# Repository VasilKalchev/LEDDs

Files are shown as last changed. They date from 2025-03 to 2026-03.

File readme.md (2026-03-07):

<p align=center>
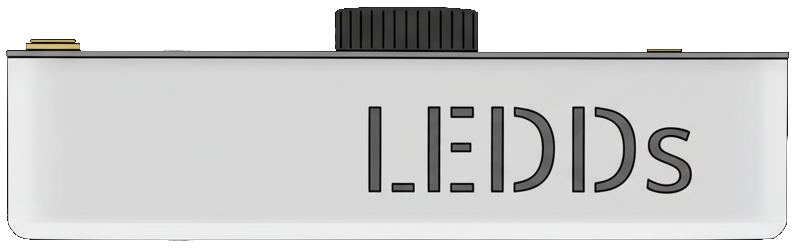
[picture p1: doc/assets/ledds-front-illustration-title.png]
LEDDs
  
</p>

<p align=center>trailing-edge dimmer for LED bulbs</p>

<div align=center>

  

</div>

**LEDDs** is an open-source hardware, DIY, smart dimmer for 230 V LED bulbs. It is built around the ESP32-C3-12F and is designed to sit on a desk or table, replacing standard inline cord switches.

The project consists of a **PCB**, a **3D-printable chassis**, and a **top plate** designed as a PCB. It runs [ESPHome](https://esphome.io) for integration with Home Assistant and features a **rotary encoder** so it can be controlled easily or used as a standalone device.

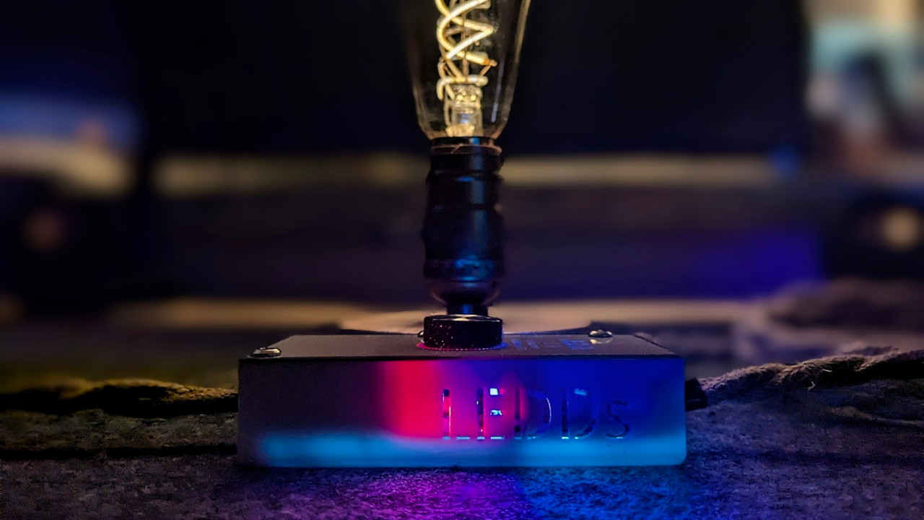
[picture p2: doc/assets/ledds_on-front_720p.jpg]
ledds


> [!CAUTION]
> **MAINS VOLTAGE:** This device operates at **230 VAC**. Touching live components can result in serious injury or death.
> * Only build if you have relevant experience with high-voltage electronics.
> * Always unplug before opening!
> * While the design includes safety features (fuse, MOVs), it is not a certified design and should be treated with caution.

## Table of contents
* [Is this project for you?](#is-this-project-for-you)
* [Why trailing-edge?](#why-trailing-edge)
* [Features](#star-features)
* [Specifications](#straight_ruler-specifications)
* [Release/fabrication of version 2.0](#releasefabrication-of-v20)
* [Repository structure](#open_file_folder-repository-structure)
* [Bill of materials](#euro-bill-of-materials)
* [Build](#hammer-build)
   * [Prerequisites](#prerequisites)
   * [1. Ordering the components](#1-ordering-the-components)
   * [2. PCB assembly instructions](#2-pcb-assembly-instructions)
   * [3. Flashing the firmware](#3-flashing-the-firmware)
   * [4. Preparing the enclosure](#4-preparing-the-enclosure)
   * [5. Final assembly](#5-final-assembly)
* [Usage](#bulb-usage)
   * [Control](#control)
   * [LED indicators](#led-indicators)
   * [Default light effects](#default-light-effects)
* [Versions, releases and compatibility](#page_with_curl-versions-releases-and-compatibility)
* [Contributing](#coffee-contributing)
* [License](#license)

---

## Is this project for you?
This project is suitable if you:
 - have experience with mains-powered electronics
 - want a LED bulbs dimmer for a desk

This project is NOT suitable if you:
 - are new to electronics
 - need a certified wall dimmer

## Why trailing-edge?
Most dimmers use **leading-edge** (TRIAC) dimming (designed for incandescent bulbs). They modulate power to the load by cutting the beginning of the AC half cycle. This creates a voltage spike that can cause buzzing and reduced lifespan in the capacitive power supplies found in LED bulbs.

**LEDDs uses trailing-edge dimming.** By using MOSFETs to cut the waveform at the *end* of the AC cycle, there isn't a positive voltage spike. This results in:
* reduced electrical noise and buzzing
* smoother dimming with reduced flicker
* lower minimum brightness levels

> The schematic and PCB can be viewed in [KiCanvas][kicanvas_v2_0].

## :star: Features
- **ESP32-C3** based with ESPHome firmware for integration with Home Assistant
- **Standalone** operation, doesn't require Home Assistant
- **Rotary encoder** control: rotate to dim, press+rotate for effects, press for on/off
- LEDs: red (rotation feedback), blue (status indicator), white (ambient)
- Included **enclosure design**: 100 mm × 51 mm × 25 mm - ideal for desk lamp modifications
- Low idle power: ~0.3 W
- Open source: MIT licensed

## :straight_ruler: Specifications

| Parameter | Value |
| --- | --- |
| Input voltage | 230 VAC |
| Maximum output power | 100 W |
| Idle power draw | ~0.3 W |
| Protections | fuse and MOVs |
| Microcontroller module | ESP32-C3-12F [^1] |
| Dimensions | 100 × 51 × 25 mm (W × D × H) |
| Connectivity | Wi-Fi, USB-C (programming) |

[^1]: Also compatible with ESP8266 ESP-12F, but not recommended.

> [!IMPORTANT]
> Designed for 230 VAC at 50 Hz.
>
> Usage with 120 VAC at 60 Hz will probably require adjusting the component values of the zero-cross and the voltage regulator circuits.

---

## Release/fabrication of v2.0

> **Status:** Verified working.
> The fabricated board from this release is fully functional. Minor issues may exist but do not affect operation: [/doc/releaselog.md v2.0][releaselog_v2_0].
>
> :memo: **Recommended for fabrication.**

<p align="center">
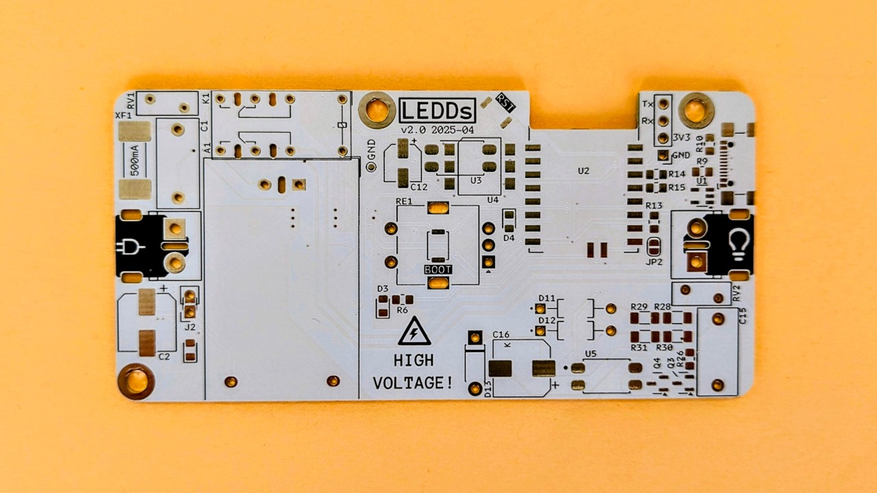
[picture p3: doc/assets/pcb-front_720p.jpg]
PCB front
  
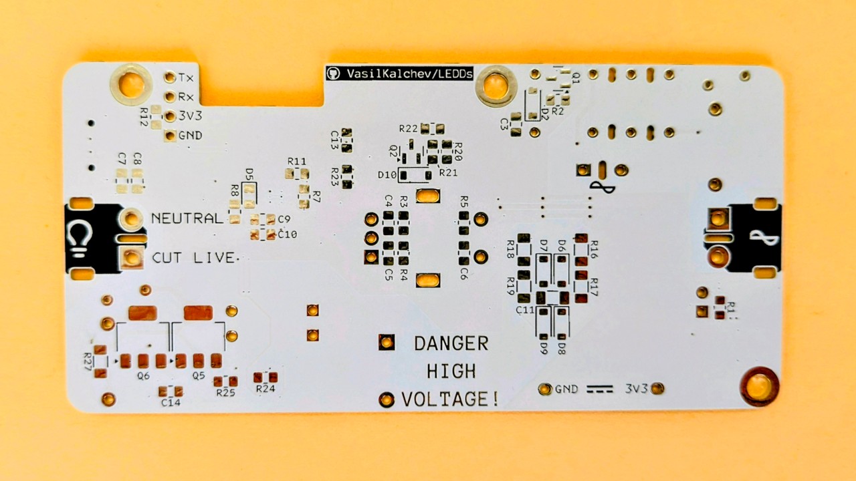
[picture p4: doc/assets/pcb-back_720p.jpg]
PCB back
  
</p>

---

## :open_file_folder: Repository structure
```

├── hw/                       # main PCB design (KiCad project)
│   ├── lib/                  # symbols and footprints
│   ├── assets/               # fonts and graphics
│   └── export/               # scripts for exporting gerbers, BOM and schematics/PCB PDFs
├── fw/                       # ESPHome YAML configurations and firmware binaries
├── doc/                      # additional documentation
│   ├── releaselog.md         # main PCB release log
│   ├── changelog.md          # main PCB change log
├── enclosure/
│   ├── chassis/              # 3D printable chassis
│   │   ├── releaselog.md     # chassis release log
│   │   ├── changelog.md      # chassis change log
│   │   ├── vX.Y-variant_a/
│   │   └── vX.Y-variant_b/
│   └── top_plate/            # top plate design (KiCad project)
│       ├── releaselog.md     # top plate release log
│       ├── changelog.md      # top plate change log
│       ├── vX.Y-variant_a/
│       └── vX.Y-variant_b/
└── img/                      # photos and renders
```

---

## :euro: Bill of materials
 - components: ~€15
 - PCB: €4 (ordered as prototype board)
 - top plate: €0-4 (can be combined with the main PCB)
 - chassis: €4-10 (when ordered)

Check out the BOM provided in the release bundle for complete components list.

## :hammer: Build

### Overview
Building LEDDs consists of four main steps:
 1. Ordering the PCB, the chassis and the components.
 2. Assembling the PCB.
 3. Flashing and configuring the firmware.
 4. Wiring and final assembly.

### Prerequisites
- skills: soldering [^2], experience with mains electricity
- tools: soldering iron, hot air gun (recommended), 3D printer or access to 3D printing service, multimeter

[^2]: Trickiest part is the USB-C port. The board can be ordered pre-assembled.

Download the [release bundle][dw_release_bundle_v2_0].

### 1. Ordering the components
  - **PCBs**: order the main PCB and the top plate PCB from your preferred fabricator
    - gerbers for JLCPCB: available in the bundle
    - for other fabricators - use KiCad to generate gerbers according to the manufacturer's instructions
  - **chassis**: choose a variant from the provided STL files

### 2. PCB assembly instructions
> [!TIP]
> Use the provided **interactive BOM** ("ibom.html") as a soldering guide.

<p align=center>
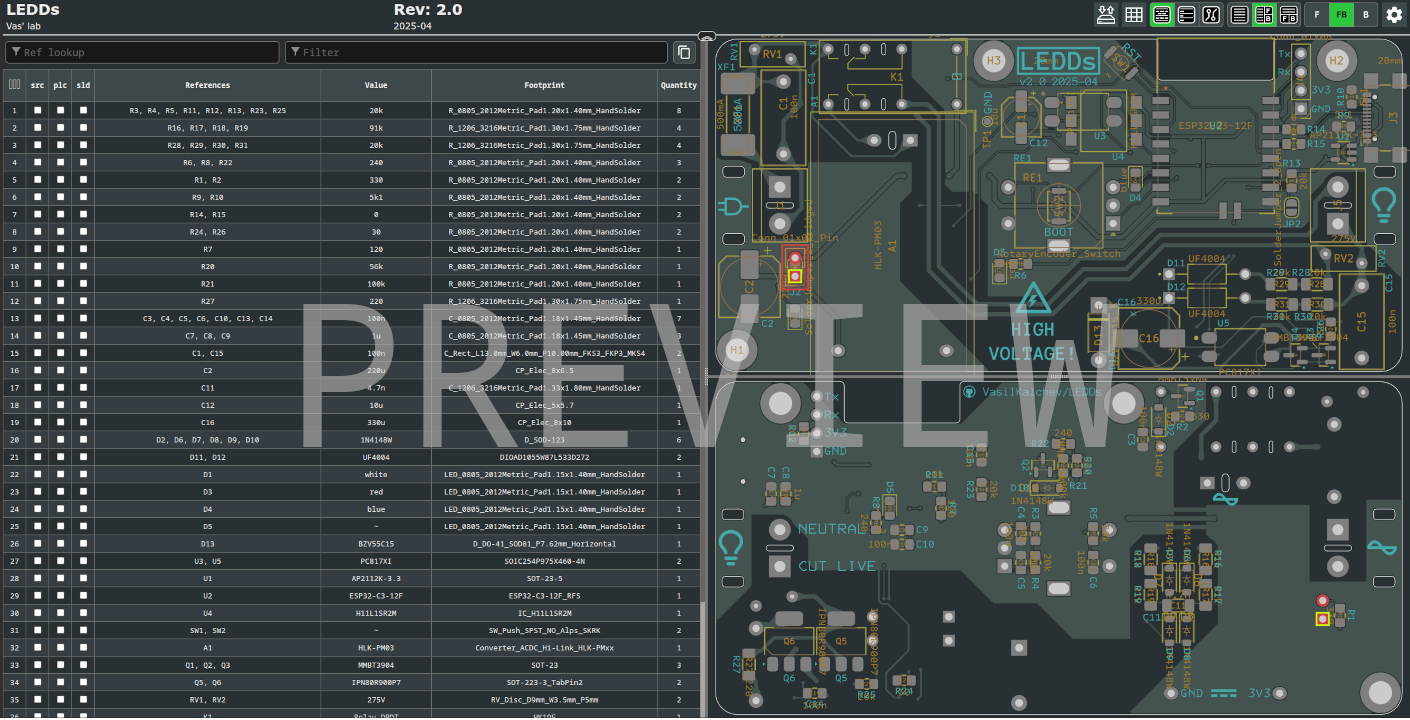
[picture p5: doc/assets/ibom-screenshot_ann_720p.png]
interactive BOM preview
  
</p>

#### Microcontroller module
<strong>ESP32-C3-12F (recommended)</strong>

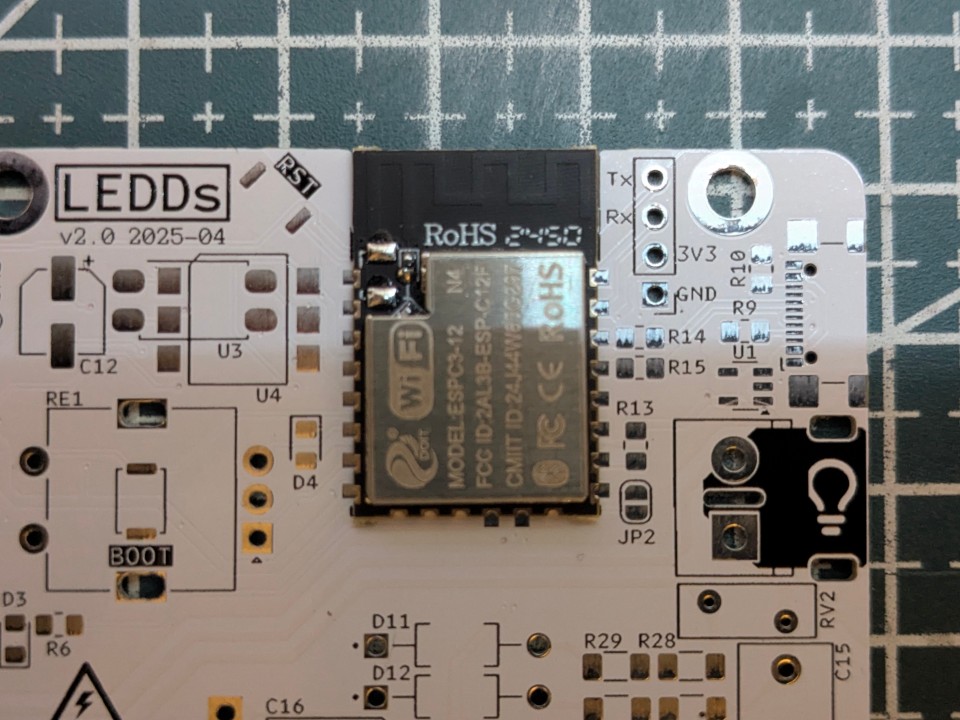
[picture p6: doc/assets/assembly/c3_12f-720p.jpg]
esp32-c3-12f


- solder R13

<details><summary><strong>ESP8266 ESP-12F (not recommended)</strong></summary>

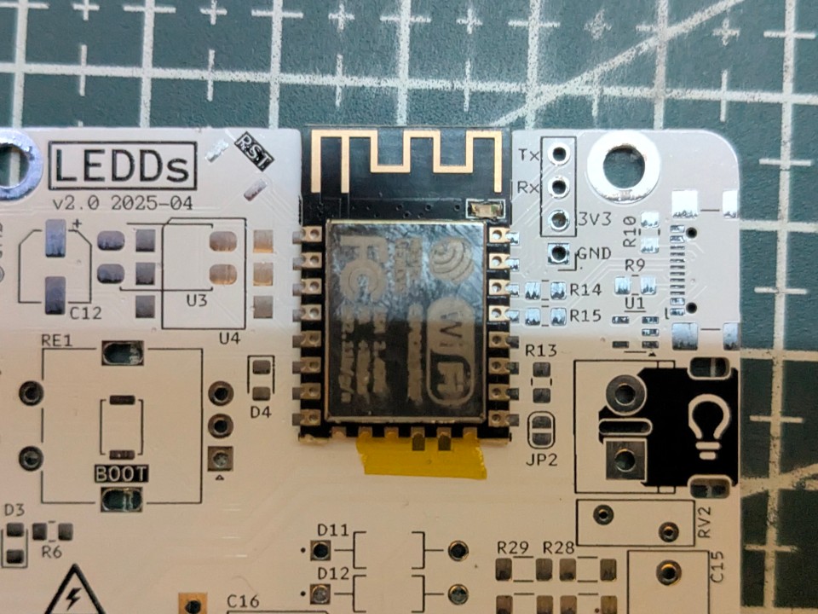
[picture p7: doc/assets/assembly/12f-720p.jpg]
esp-12f


- insulate pins 12 and 13 from the PCB pads using kapton/electrical tape
- solder JP2
- don't solder R13
- don't solder R6 and D3 ("led_1")
- don't solder R8 and D5 ("led_3")

ESP8266 doesn't support native USB and requires an external USB to serial adapter for programming.

</details>

#### Zero-cross optoisolator
The PCB has footprints for a choice between 2 optoisolators that connect the zero-cross signal to the MCU.

<strong>H11L1SR2M</strong>

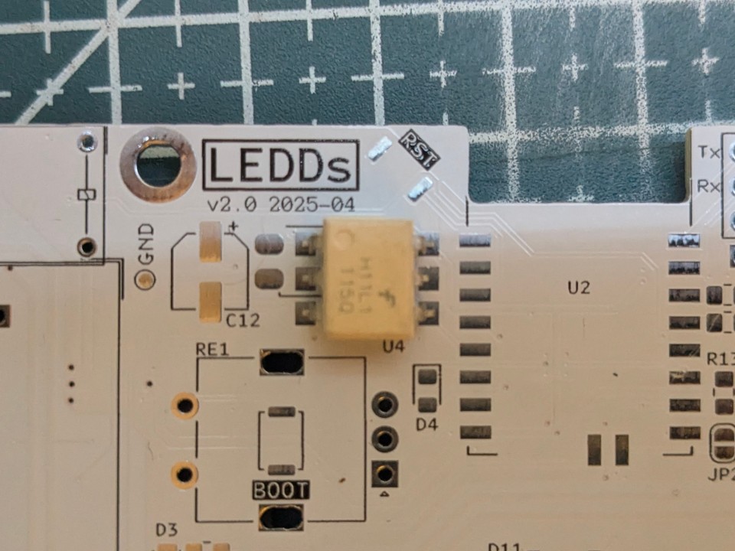
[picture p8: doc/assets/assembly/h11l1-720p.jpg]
h11l1


 - solder the optoisolator on footprint U4
 - solder C13

<details><summary><strong>PC817XI (not recommended)</strong></summary>

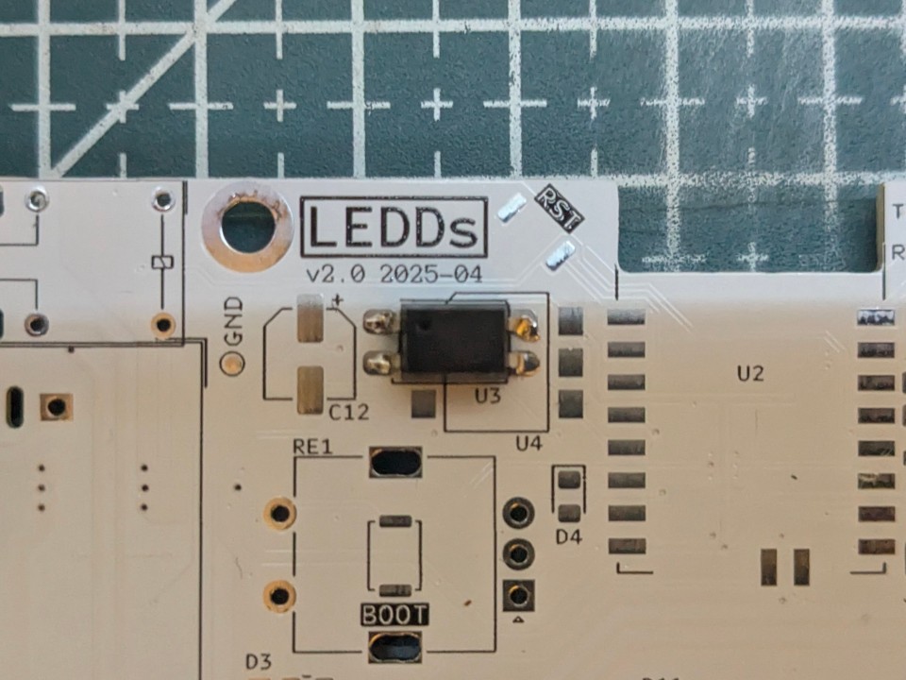
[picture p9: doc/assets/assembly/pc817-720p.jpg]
pc817


- solder the optoisolator on footprint U3
- no need to solder C13

This optoisolator is the same as the one used for controlling the MOSFET's gate, but didn't work well for the zero-cross circuit.

</details>

#### Skipping the relay
The relay is used to power off the mains part of the circuit when the load is turned off. This is intended as a peace of mind feature and can be omitted.

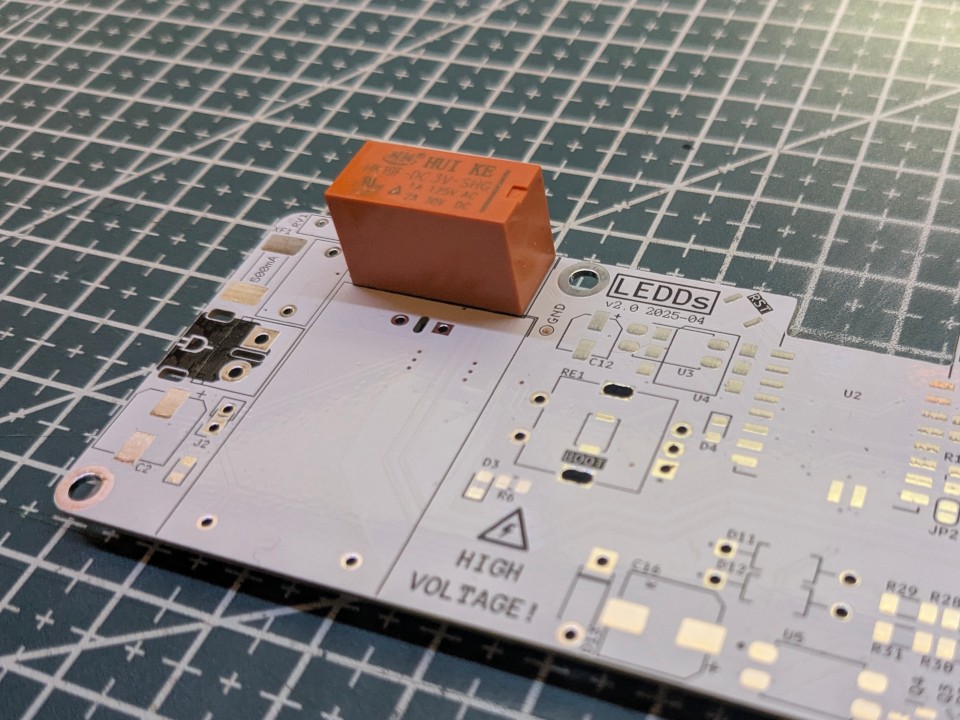
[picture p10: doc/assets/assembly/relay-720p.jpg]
relay


 - use a wire to short pin 11 to 14
 - use a wire to short pin 21 to 24
 - no need to solder C3, D2, R2 and Q1

#### Skipping the rotary encoder
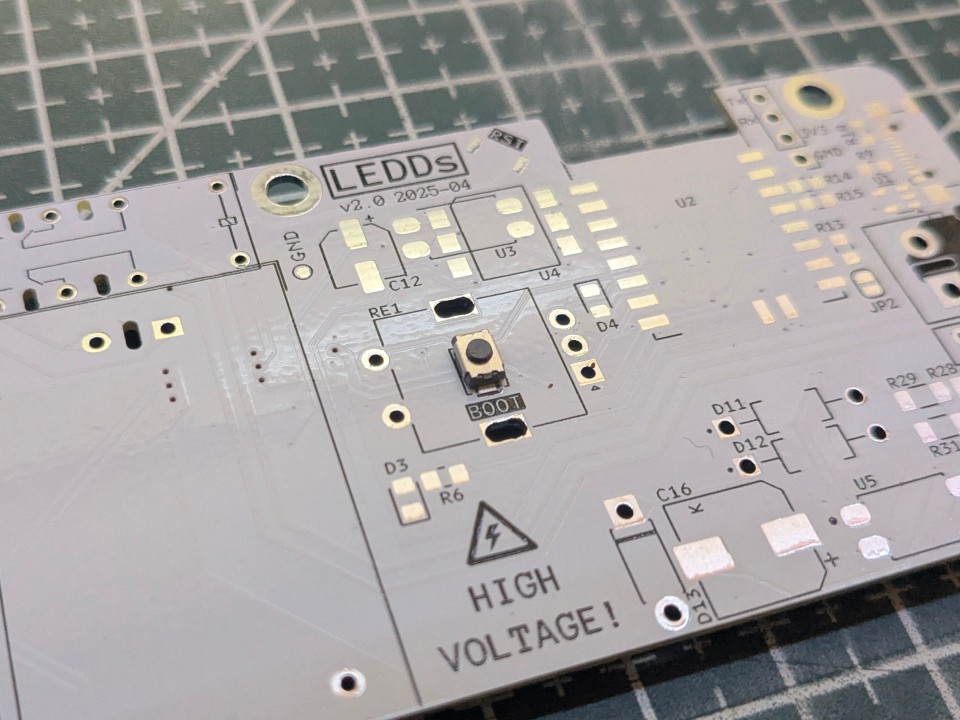
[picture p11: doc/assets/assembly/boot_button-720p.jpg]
boot button


If the rotary encoder is not required - solder a push button (SW2) so boot mode can be entered manually.

 - no need to solder R3, R4, C4, C5 and C6

A modified top plate (without a hole in the middle) is recommended for safety reasons (not currently available).

#### Using the UART header instead of the USB for programming *(not tested)*
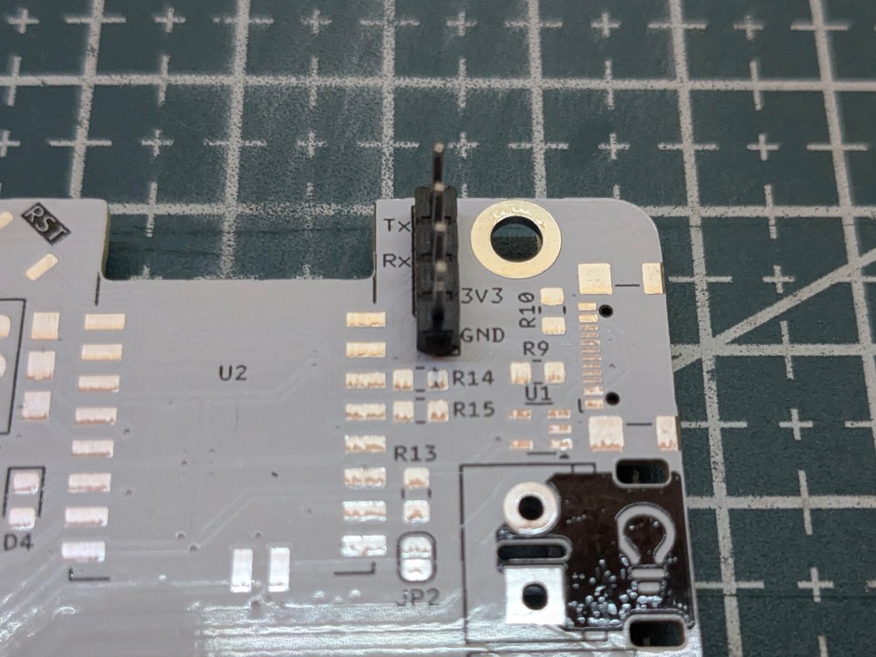
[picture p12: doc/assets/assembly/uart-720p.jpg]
uart


 - solder R12
 - solder header J4
 - no need to solder R9 and R10

Use a USB to serial adapter.

### 3. Flashing the firmware
 - Connect to the board via USB-C.
 - Use [ESPHome's web flasher](https://web.esphome.io/) to upload one of the provided firmware binaries.
   - hass.bin: Home Assistant + rotary encoder
   - web_server.bin: self hosted web server + rotary encoder
   - standalone: rotary encoder only
 - Set your Wi-Fi credentials using the ESPHome web flasher.
 - Test before wiring.

> [!TIP]
> The YAML configurations of the provided binaries are available under [/fw/esphome/yaml/](/fw/esphome/yaml/).

### 4. Preparing the enclosure
- plastic chassis: install the heat-set threaded inserts in the holes using a soldering iron
- resin chassis: no preparation needed

### 5. Final assembly
 - Mount a knob to the rotary encoder.
 - Place the PCB inside the chassis.
 - Screw the mains power cable to the terminal on the left (marked with a power plug). **Don't connect power until fully assembled.**
 - Screw the lamp socket cable to the terminal on the right (marked with a bulb).
 - Pass the screws through the top plate and place the spacers on the screws.
 - Screw the top plate through the PCB into the chassis.

## :bulb: Usage
### Control
**Directly** *(possible with all firmware variants)*:
 - **press**: on/off
 - **rotate**: brightness adjustment
 - **press + rotate**: cycle lighting effects

**Home Assistant** *(included in hass.bin)*:

Integrating the device in Home Assistant: https://esphome.io/guides/getting_started_hassio/#connecting-your-device-to-home-assistant.

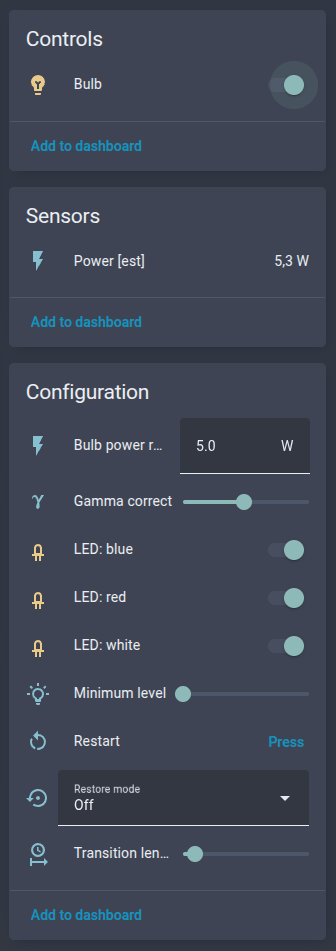
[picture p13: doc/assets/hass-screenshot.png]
screenshot of the device in Home Assistant


The "Configuration" section allows customization of the device:
 - **Bulb power rating**: input the power rating of the bulb, this is used for the power estimation sensor ("Power \[est\]").
 - **Gamma correct**: Adjust the dimming curve to appear linear to the human eye.
 - **Minimum level**: The lowest level at which the bulb emits light. *Note: this value needs to be updated every time gamma correction is changed.*
 - **Restore mode**: Initial state of the bulb when powered.
 - **Transition length**: How fast the bulb changes brightness in milliseconds.
 - **LED: red/blue/white**: set the ambient brightness of the LEDs.

**Web server** *(included in web_server.bin)*:
> This is useful if you don't have Home Assistant, but want to control the device remotely.

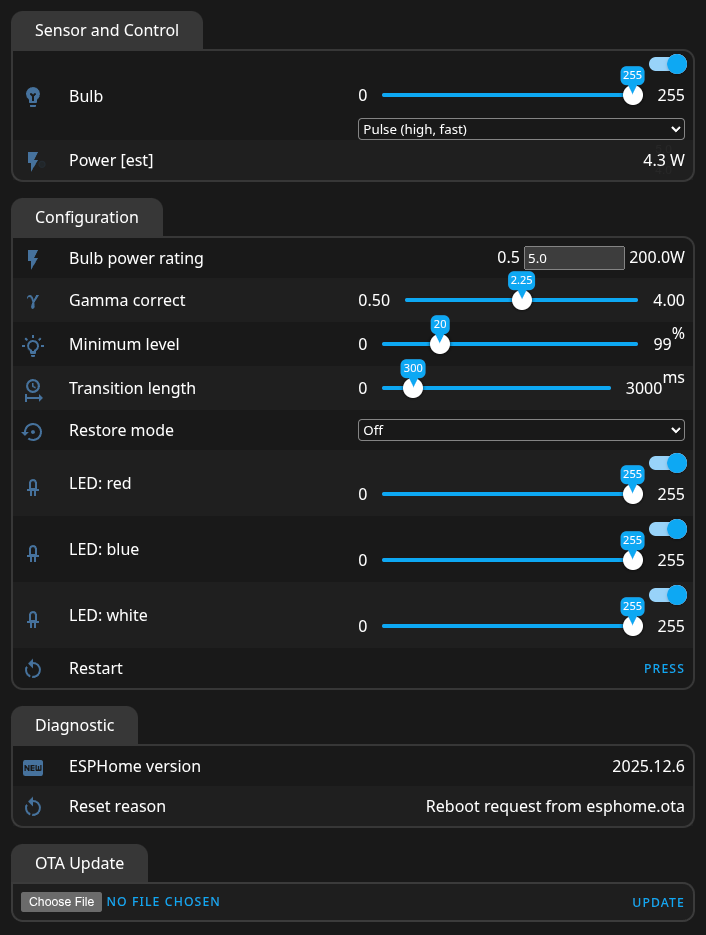
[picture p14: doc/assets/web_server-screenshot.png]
screenshot of the web UI


### LED indicators
There are three LEDs on the board:
 - **red (top, led_1):** ambient / rotation feedback
 - **blue (top, led_2):** ambient / status indicator
 - **white (bottom, led_3):** ambient

### Default light effects
Light effects can be cycled with the rotary encoder or chosen directly from a UI.

 - Pulse (low, fast)
 - Pulse (low, slow)
 - Pulse (high, fast)
 - Pulse (high, slow)
 - Pulse (full, fast)
 - Pulse (full, slow)
 - Flicker (soft)
 - Flicker (intense)

<!--
<div>
<p align="center">
  <img src="/doc/assets/effect-pulse_low_fast.gif" alt="" title="Pulse (low, fast)" width="25%" />
  <img src="/doc/assets/effect-pulse_low_slow.gif" alt="" title="Pulse (low, slow)" width="25%" />
  <img src="/doc/assets/effect-pulse_high_fast.gif" alt="" title="Pulse (high, fast)" width="25%" />
  <img src="/doc/assets/effect-pulse_high_slow.gif" alt="" title="Pulse (high, slow)" width="25%" />
</p>
<p align="center">
  <img src="/doc/assets/effect-pulse_full_fast.gif" alt="" title="Pulse (full, fast)" width="25%" />
  <img src="/doc/assets/effect-pulse_full_slow.gif" alt="" title="Pulse (full, slow)" width="25%" />
  <img src="/doc/assets/effect-flicker_soft.gif" alt="" title="Flicker (soft)" width="25%" />
  <img src="/doc/assets/effect-flicker_intense.gif" alt="" title="Flicker (intense)" width="25%" />
</p>
</div>
-->

## :page_with_curl: Versions, releases and compatibility
Each fabrication run results in a **GitHub release**.
- Semantic versioning (major.minor), no patch versions.
- PCB, chassis, and top plate are versioned independently.
- Same **major versions fit together**.

## :coffee: Contributing
Every type of contribution is welcome, like improvements or corrections to the:
- schematic/PCB design
- documentation
- enclosure (chassis and top panel) design
- ESPHome configuration

Contributions can be made as improvements or as variants (e.g. different enclosure design, ESPHome configuration, etc.).

```mermaid
gitGraph
    commit tag: "v1.0"
    branch improve_x
    checkout improve_x
    commit id: "Improve x"
    commit id: "Re-generate exports"
    commit id: "Update board documentation"
    checkout main
    merge improve_x tag: "v1.1"
    branch replace_y
    checkout replace_y
    commit id: "Replace y"
    commit id: "Generate exports"
    commit id: "Compile binaries"
    commit id: "Update all documentation"
    checkout main
    merge replace_y tag: "v2.0"
```

You're welcome to post your builds in [Discussions: Show and tell](https://github.com/VasilKalchev/LEDDs/discussions/categories/show-and-tell).

## License
This project is licensed under the **MIT License**.

---

**Disclaimer**: This project involves mains voltage electricity. The author assumes no liability for injury, damage, or regulatory violations. Build and use at your own risk. Ensure compliance with local electrical codes and regulations.

<!-- current version links -->

[kicanvas_v2_0]: https://kicanvas.org/?github=https%3A%2F%2Fgithub.com%2FVasilKalchev%2FLEDDs%2Ftree%2Fv2.0%2Fhw
[dw_release_bundle_v2_0]: https://github.com/VasilKalchev/LEDDs/releases/download/v2.0/LEDDs.v2.0.zip

[releaselog_v2_0]: /doc/releaselog.md#v20---2025-04-02

<!-- /current version links -->

<!-- checklist
<details>
<summary>/readme.md checklist</summary>

 - [x] set release result (template in releaselog.md)
 - [x] update the sections as needed
 - [x] comment out this checklist

</details>

-->
<!-- /checklist -->

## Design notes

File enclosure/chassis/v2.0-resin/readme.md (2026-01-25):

[Tinkercad: LEDDs chassis v2.0 (resin)](https://www.tinkercad.com/things/dSsVzKjQB6I-ledds-chassis-v20-resin)

<div>
<p align="center">
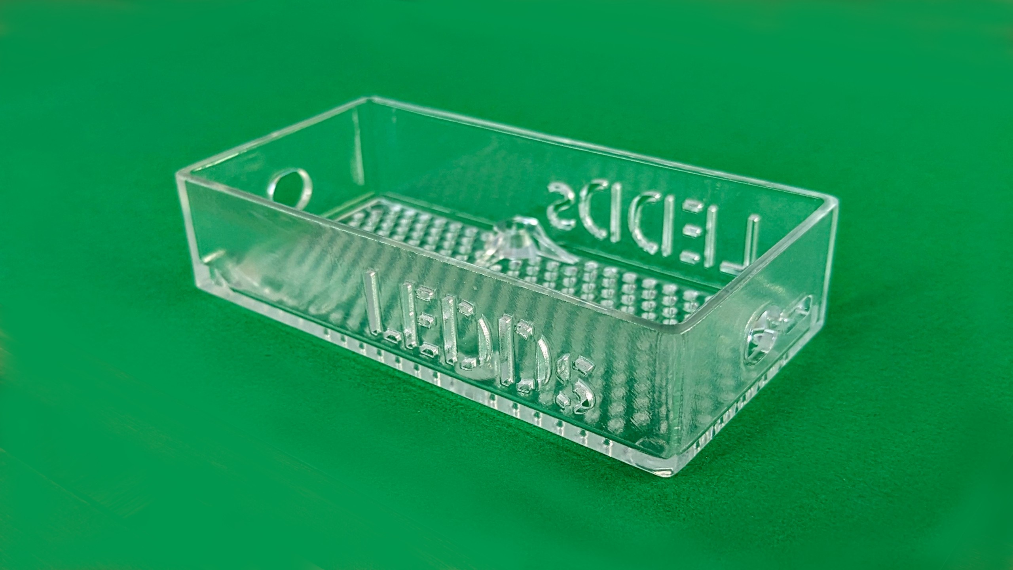
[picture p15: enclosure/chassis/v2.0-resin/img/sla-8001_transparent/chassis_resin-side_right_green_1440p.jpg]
chassis side
  
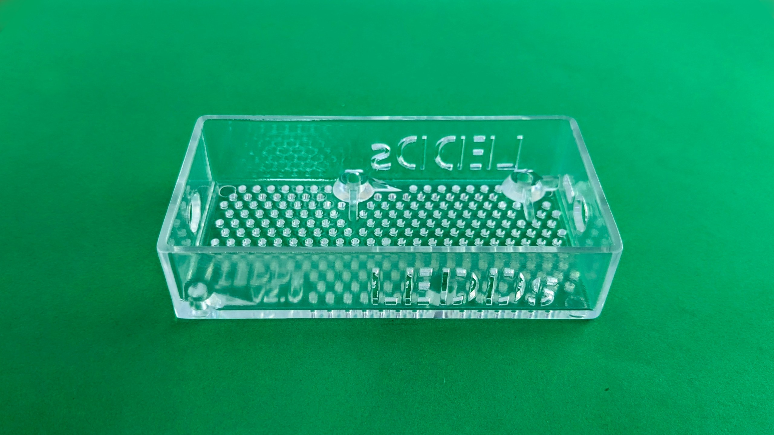
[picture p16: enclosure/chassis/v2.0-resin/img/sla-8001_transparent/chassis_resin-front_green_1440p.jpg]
chassis front
  
</p>
<p align="center">
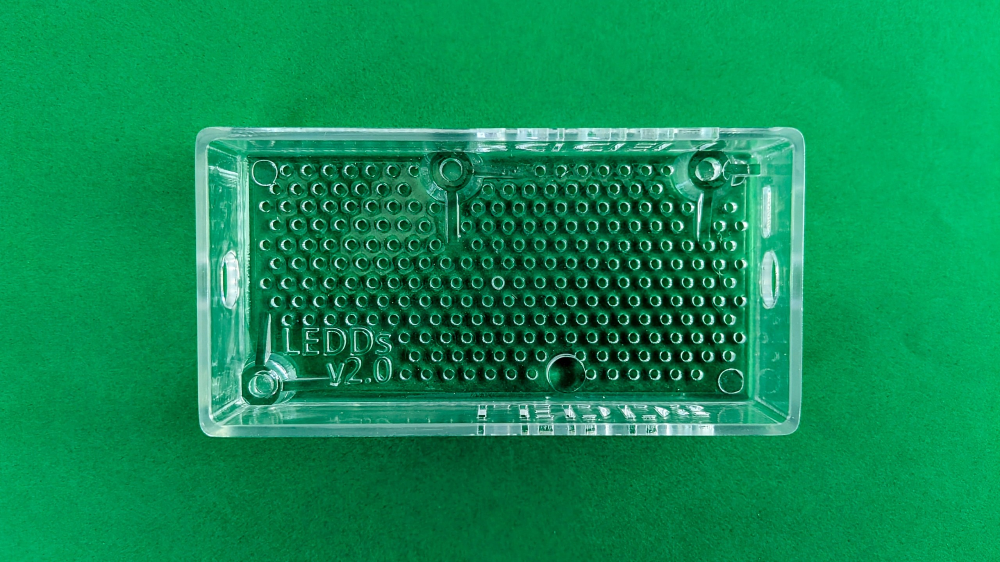
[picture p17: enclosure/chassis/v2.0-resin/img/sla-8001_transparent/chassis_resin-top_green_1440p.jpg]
chassis top
  
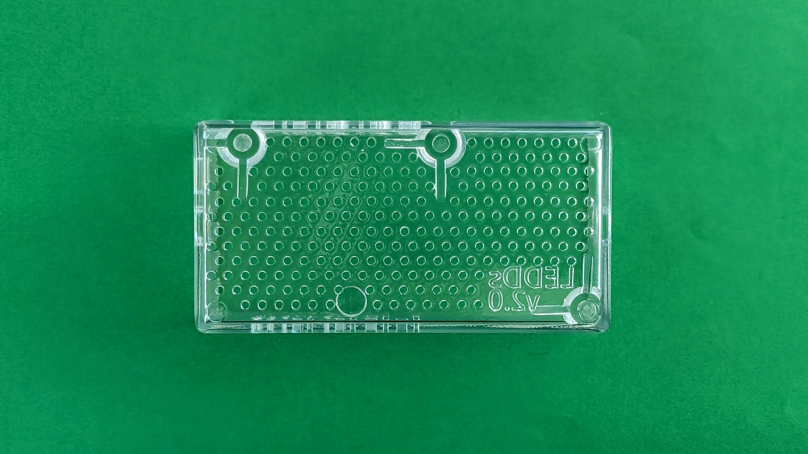
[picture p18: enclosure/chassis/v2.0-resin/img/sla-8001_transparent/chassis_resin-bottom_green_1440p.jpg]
chassis bottom
  
</p>
</div>

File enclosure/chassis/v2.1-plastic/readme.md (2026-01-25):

[Tinkercad: LEDDs chassis v2.1 (plastic)](https://www.tinkercad.com/things/8mwNKOLO64o-ledds-chassis-v21-plastic)

<div>
<p align="center">
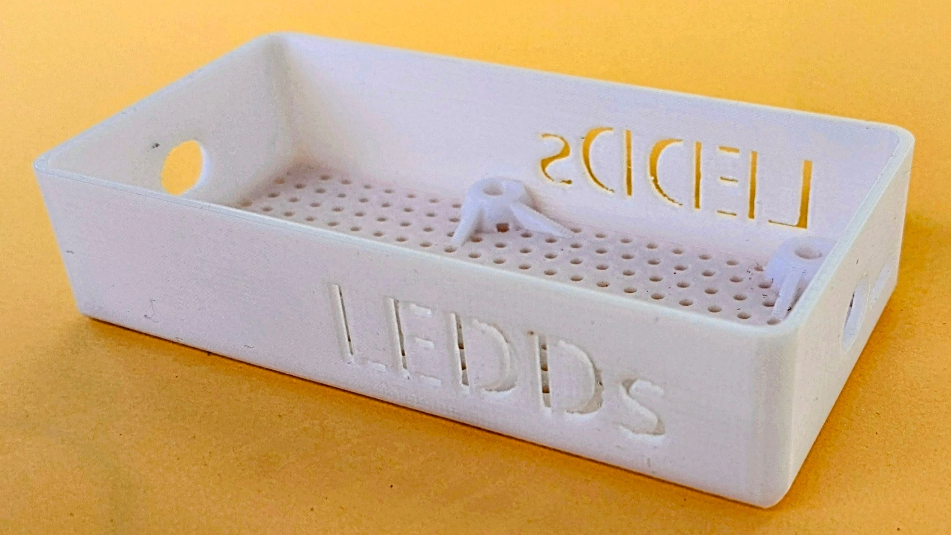
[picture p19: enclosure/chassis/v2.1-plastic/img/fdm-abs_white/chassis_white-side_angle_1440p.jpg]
chassis side
  
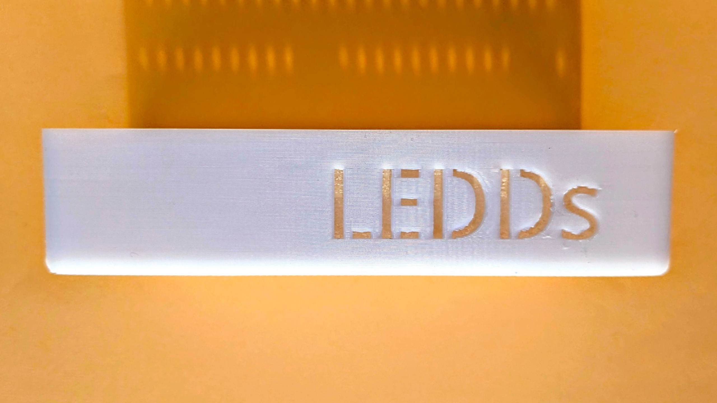
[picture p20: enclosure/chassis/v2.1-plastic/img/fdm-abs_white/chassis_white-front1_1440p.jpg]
chassis front
  
</p>
<p align="center">
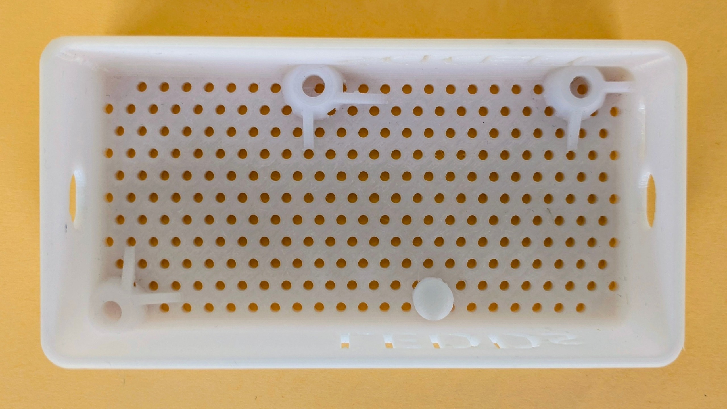
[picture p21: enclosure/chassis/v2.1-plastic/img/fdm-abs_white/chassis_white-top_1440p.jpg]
chassis top
  
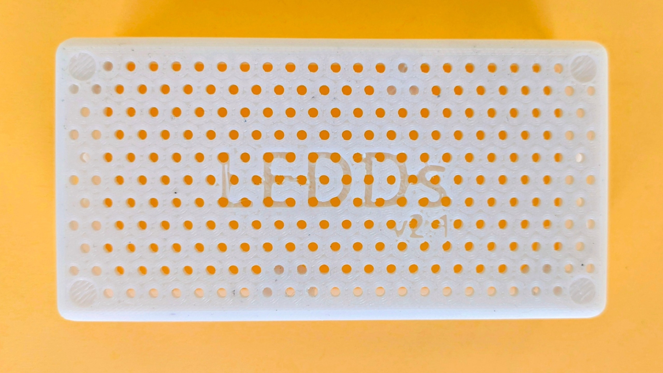
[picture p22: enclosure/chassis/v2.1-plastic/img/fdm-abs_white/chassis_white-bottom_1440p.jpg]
chassis bottom
  
</p>
</div>

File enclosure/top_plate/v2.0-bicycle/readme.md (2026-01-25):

<figure>
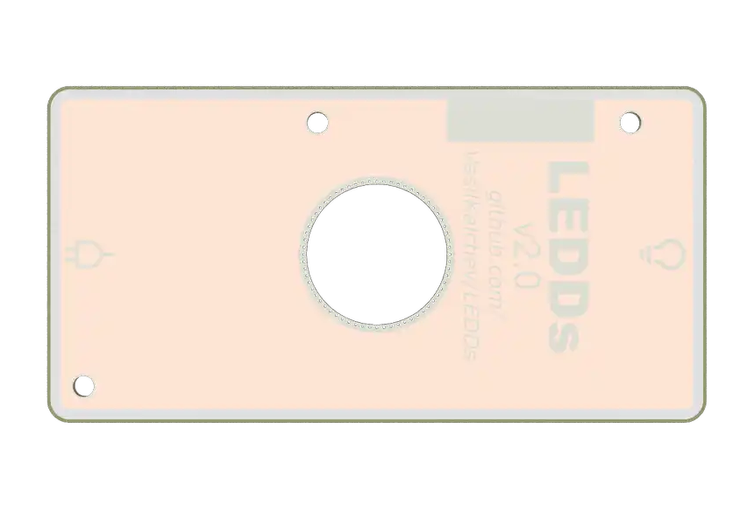
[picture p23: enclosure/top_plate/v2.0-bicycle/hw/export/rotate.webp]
rotating PCB render
  
<!--   <figcaption>smaller</figcaption> -->
</figure>

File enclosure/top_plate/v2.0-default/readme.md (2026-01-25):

<figure>
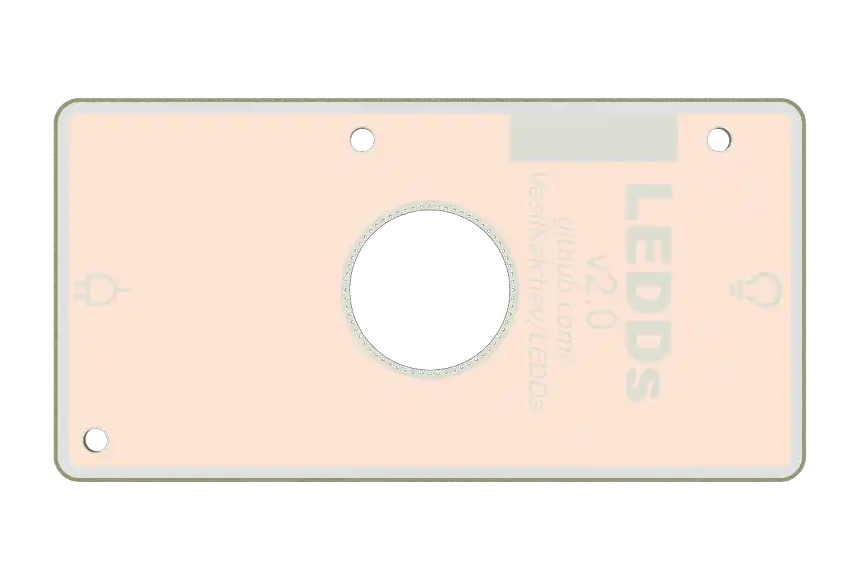
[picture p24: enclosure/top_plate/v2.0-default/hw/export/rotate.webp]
rotating PCB render
  
<!--   <figcaption>larger</figcaption> -->
</figure>

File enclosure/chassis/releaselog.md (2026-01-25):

# Chassis release log
Printing results.

## v2.1-plastic (FDM - ABS, white) - 2025-04-20

> The printed chassis from version 2.1 works without problems!
>
> :tada: Recommended for printing.

### Properties:
 - Fabricator: JLCPCB
 - Dimensions: 10×5.1×2.3cm
 - Volume: 19.46cm³
 - Surface area: 246.48cm²
 - 3D Technology: FDM (plastic)
 - Material: ABS
 - Colors: white
 - Surface finish: no

## v2.0-resin (SLA - 8001 resin, transparent) - 2025-04-03

> The printed chassis from version 2.0 works, but has some minor issues.
>
> :grey_exclamation: Obsolete.

### Properties:
 - Fabricator: JLCPCB
 - Dimensions: 10×5.1×2.3cm
 - Volume: 21.15cm³
 - Surface area: 248.42cm²
 - 3D Technology: SLA (resin)
 - Material: 8001 resin
 - Colors: transparent
 - Surface finish: oil spraying

### Problems
#### Minor
 - USB receptacle barely fits in the cutout
 - transparency doesn't go well with colored top plate

## v2.0-plastic (FDM - TPU translucent) - 2025-04-03

> The printed chassis from version 2.0 works, but has some minor issues.
>
> :grey_exclamation: Obsolete.

### Properties:
 - Fabricator: JLCPCB
 - Dimensions: 10×5.1×2.3cm
 - Volume: 21.15cm³
 - Surface area: 248.42cm²
 - 3D Technology: FDM (plastic)
 - Material: TPU
 - Colors: translucent
 - Surface finish: no

### Problems
#### Minor
 - USB receptacle barely fits in the cutout
 - the material is not suitable for a case
 - the color doesn't go well with the top plate

## v1.0 (FDM - PLA, white) - 2025-02-17

> The printed chassis from version 1.0 works, but has some minor issues.
>
> :grey_exclamation: Obsolete.

### Properties:
 - Fabricator: JLCPCB
 - Dimensions: 10×5.1×2.3cm
 - Volume: 22.55cm³
 - Surface area: 232.44cm²
 - 3D Technology: FDM (plastic)
 - Material: PLA
 - Colors: white
 - Surface finish: no

### Problems:
#### Minor
 - the programming header is not reachable through the cutout
 - the side name cutout is partly covered by the AC-DC converter

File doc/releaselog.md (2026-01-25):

# Release log

## v2.0 - 2026-01-26
### Hightlights
 - Switched MCU module to **ESP32-C3-12F**.
 - Added **USB-C** port for programming.

### Changes
 - Replaced module ESP-12 (ESP8266) with module ESP32-C3-12F (ESP32-C3).
 - Added USB-C.
 - Added 3.3 V linear regulator for powering the MCU through the USB only.
 - PCB layout adjustments.

### Compatibility notes
 - Older enclosures (chassis and top plate) from v1.y are not compatible with the new PCB.
 - UART header remains available, but the auto-programming circuit is removed.

### Upgrade impact
 - Firmware must target ESP32-C3.
 - Devices can be programmed directly over USB-C.

---

<p align="center">
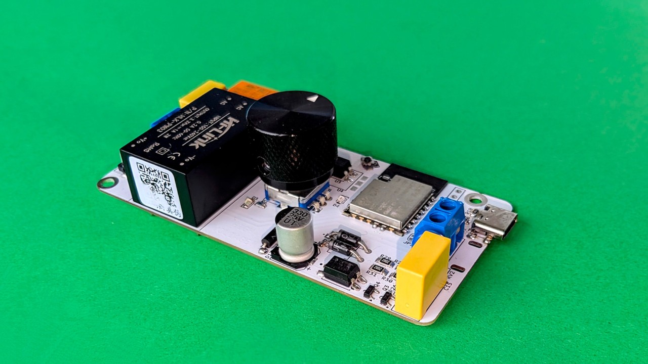
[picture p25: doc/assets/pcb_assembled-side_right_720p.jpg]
assebmled main PCB
  
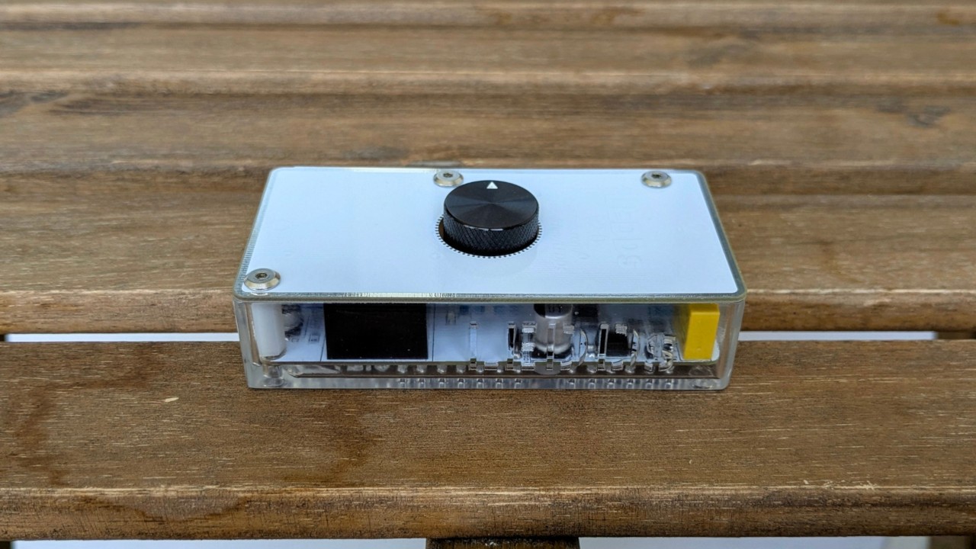
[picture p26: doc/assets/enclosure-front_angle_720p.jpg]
assembled project
  
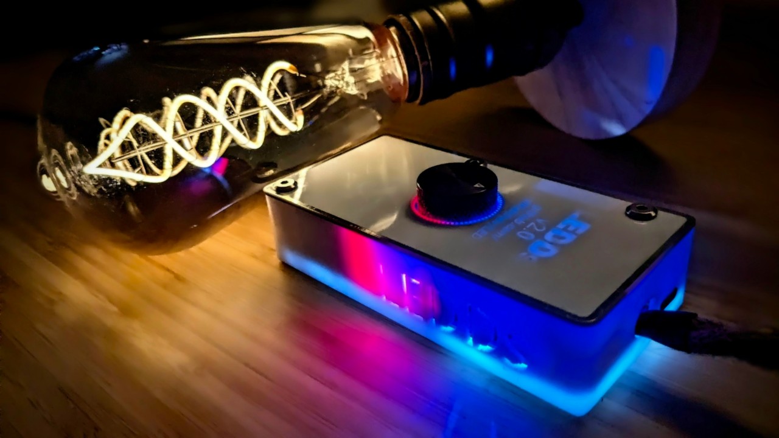
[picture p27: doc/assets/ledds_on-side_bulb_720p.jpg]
turned on
  
</p>


> **Status:** Verified working.
> The fabricated board from this release is fully functional. Minor issues may exist but do not affect operation.
>
> :memo: **Recommended for fabrication.**

### Fabbrication properties:
 - Fabricator: JLCPCB
 - Material: FR4 (Tg 135)
 - Layers: 2
 - **PCB thickness: 1 mm** [^1]
 - Solder mask color: white
 - Silkscreen: black
 - Surface finish: HASL (with lead)
 - Copper weight: 1 oz
 - Via covering: tented
 - Board outline tolerance: +-0.2 mm
 - Appearance quality: IPC Class 2 Standard
 - Silkscreen technology: Ink-jet/screen printing

### Issues
#### Minor
 - module ESP32-C3-12F isn't an official module and isn't available from distributors
 - red LED is only visible from one side

---

## v1.0 - 2025-02-17

<p align="center">
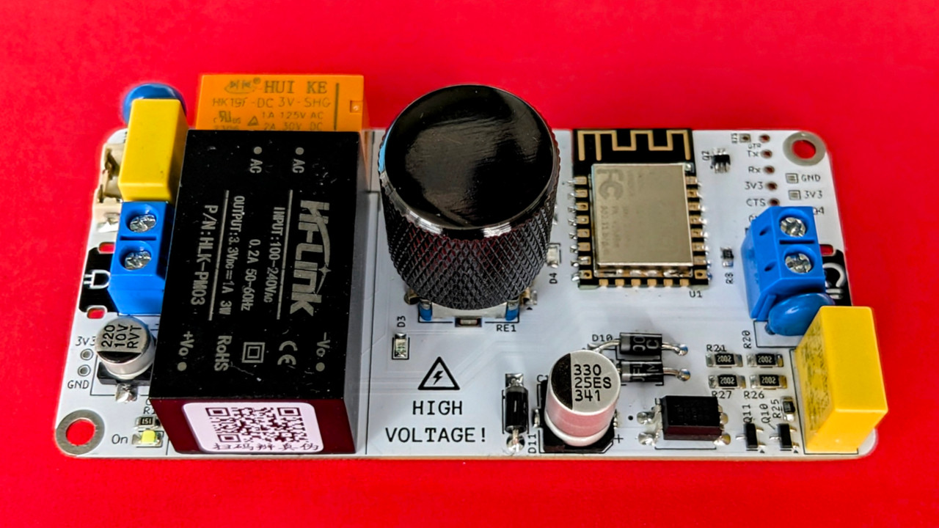
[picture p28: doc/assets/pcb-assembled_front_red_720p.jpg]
PCB - assembled, front PCB - assembled, side
  
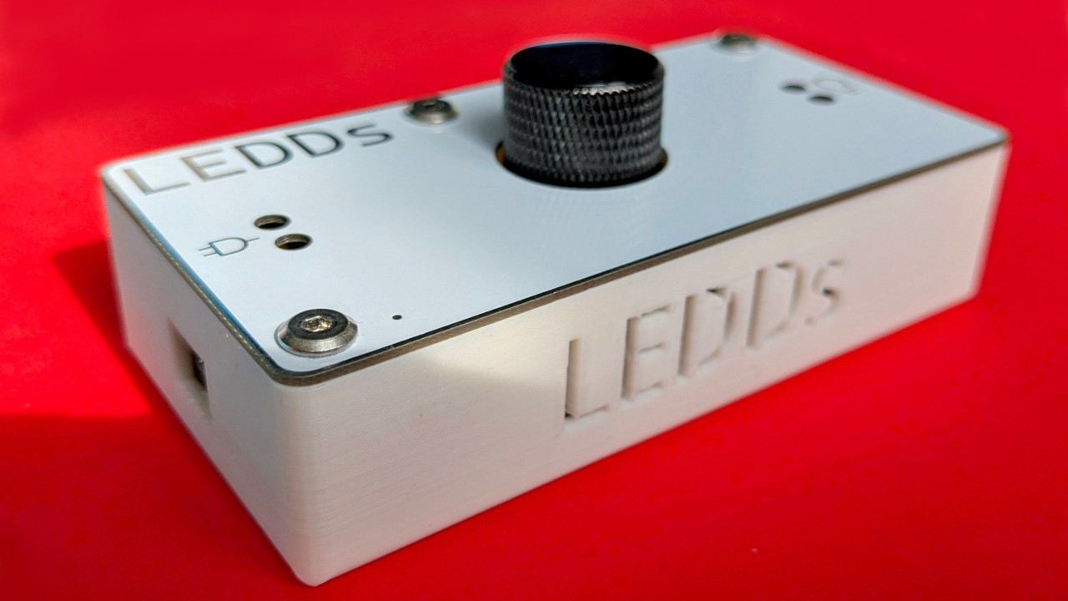
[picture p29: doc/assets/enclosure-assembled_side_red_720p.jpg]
Enclosure - assembled, side
  
</p>

---


> **Status:** Verified working.
> The fabricated board from this release is fully functional. Minor issues may exist but do not affect operation.
>
> :grey_exclamation: **Obsolete!**

### Fabrication properties:
 - Fabricator: JLCPCB
 - Material: FR4 (Tg 135)
 - Layers: 2
 - **PCB thickness: 1 mm** [^1]
 - Solder mask color: white
 - Silkscreen: black
 - Surface finish: HASL (with lead)
 - Copper weight: 1 oz
 - Via covering: tented
 - Board outline tolerance: +-0.2 mm
 - Appearance quality: IPC Class 2 Standard
 - Silkscreen technology: Ink-jet/screen printing

### Issues
#### Minor
 - ESP8266 is an obsolete MCU
 - R14/15/18/19 have non-standard values
 - zip-tie holes are too small
 - silkscreen with GitHub link is barely readable
 - relay pins cutouts are very close to the edge of the board
 - GPIO2 is connected to both led_1 and ESP-12's on-board LED

[^1]: Important for fit with the height of the chassis and the length of the spacers.

<!-- checklist

<details>
<summary>/releaslog.md checklist</summary>

 - [x] complete [/hw/project_checklist.md](/hw/project_checklist.md)
 - [x] fabricate
 - [x] assembly and test

 - [ ] FW

 - [x] add version with changes to [/doc/changelog.md](/doc/changelog.md)
 - [x] add version with fabrication result to [/doc/releaselog.md](/doc/releaselog.md)

 - [ ] use the scripts in [/hw/export/] to generate "release" files
 - [ ] complete [/doc/assets/readme/readme.md](/doc/assets/readme/readme.md) checklist
 - [ ] complete [/readme.md](/readme.md) checklist

 - [x] mark older boards of this major version as obsolete (in [/doc/releaselog.md](/doc/releaselog.md) and in repository releases)

 - [x] delete [/hw/project_checklist.md](/hw/project_checklist.md)

List of checklists inside the repository:
 - [/hw/project_checklist.md](/hw/project_checklist.md)
 - [/fw/readme.md](/fw/readme.md)
 - [/doc/assets/readme/readme.md](/doc/assets/readme/readme.md)
 - [/readme.md](/readme.md)

</details>

-->

<!-- release assessment templates (new)

![Status: Great](https://img.shields.io/badge/Great-limegreen?style=for-the-badge&label=Release/fabrication%20result)
> **Status:** Great release.
> The fabricated board works without any known issues.
>
> :tada: **Recommended for fabrication!** | :grey_exclamation: **Obsolete!**

---

![Status: Stable](https://img.shields.io/badge/Stable-brightgreen?style=for-the-badge&label=Release/fabrication%20result)
> **Status:** Verified working.
> The fabricated board from this release is fully functional. Minor issues may exist but do not affect operation: [releaselog](/doc/releaselog.md#vXY---202Y-MM-DD).
>
> :memo: **Recommended for fabrication.** | :grey_exclamation: **Obsolete!**

---

![Status: With issues](https://img.shields.io/badge/Functional_(w%2F_Caveats)-yellow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)
> **Status:** Functional with modifications.
> This board works, but has signifacant issues: [releaselog](/doc/releaselog.md#vXY---202Y-MM-DD).
>
> :grey_exclamation: Use [version X.Y] for fabrication or wait for a fix.

---

![Status: Broken](https://img.shields.io/badge/Do_Not_Use-firebrick?style=for-the-badge&label=Release/fabrication%20result)

> **Status:** Critical faults.
> The fabricated board from this release has significant design flaws and does not function correctly: [releaselog](/doc/releaselog.md#vXY---202Y-MM-DD).
>
> :stop_sign: **Do not fabricate.** Use [Version X.Y] instead.

---

![Status: WIP](https://img.shields.io/badge/In_development-lightgrey?style=for-the-badge&label=Release/fabrication%20result)
> **Status:** Work in progress.
> This branch is currently in active development and may be unstable.
>
> :hourglass_flowing_sand: **Wait for release** or use [Version X.Y].

---

![Status: Untested](https://img.shields.io/badge/Untested_fix-blueviolet?style=for-the-badge&label=Release/fabrication%20result)
> **Status:** Design fix (not yet fabricated).
> This release patches bugs found in vX.X. The design is theoretically correct but has not been physically verified.
>
> :memo: Check the latest [release note of this version](https://github.com/VasilKalchev/LEDDs/releases/tag/vX.Y) for a possible update on the fabrication status.

-->

<!-- release assessment templates (old)

<details>
<summary>release assessment templates</summary>

![bad fabrication](https://img.shields.io/badge/bad-firebrick?style=for-the-badge&label=Release/fabrication%20result)
> The fabricated board from release vX.Y doesn't work: [releaselog](/doc/releaselog.md#vXY---202Y-MM-DD).
>
> :grey_exclamation: Use [version X.Y] for fabrication or wait for a fix.

---

![poor fabrication](https://img.shields.io/badge/poor-orangered?style=for-the-badge&label=Release/fabrication%20result)
> The fabricated board from release vX.Y works, but has significant problems: [releaselog](/doc/releaselog.md#vXY---202Y-MM-DD).
>
> :grey_exclamation: Use [version X.Y] for fabrication or wait for a fix.

---

![average fabrication](https://img.shields.io/badge/average-yellow?style=for-the-badge&label=Release/fabrication%20result)
> The fabricated board from release vX.Y works, but has some issues: [releaselog](/doc/releaselog.md#vXY---202Y-MM-DD).
>
> :grey_exclamation: Use [version X.Y] for fabrication or wait for a fix.

---

![good fabrication](https://img.shields.io/badge/good-greenyellow?style=for-the-badge&label=Release/fabrication%20result)

> The fabricated board from release vX.Y works; it has some minor issues: [releaselog](/doc/releaselog.md#vXY---202Y-MM-DD).
>
> :memo: Recommended for fabrication! | :grey_exclamation: Obsolete!

---

![very good fabrication](https://img.shields.io/badge/very%20good-lawngreen?style=for-the-badge&label=Release/fabrication%20result)

> The fabricated board from release vX.Y works; it has a few minor issues: [releaselog](/doc/releaselog.md#vXY---202Y-MM-DD).
>
> :memo: Recommended for fabrication! | :grey_exclamation: Obsolete!

---

![great fabrication](https://img.shields.io/badge/great-limegreen?style=for-the-badge&label=Release/fabrication%20result)
> The fabricated board from release vX.Y works without any known issues!
>
> :tada: Recommended for fabrication! | :grey_exclamation: Obsolete!

---

![in development](https://img.shields.io/badge/in_development-dimgrey?style=for-the-badge&label=Release/fabrication%20result)
> This version is currently in development...
>
> :hourglass_flowing_sand: Wait for the release or use [version X.Y] for fabrication.

---

![will not fabricate](https://img.shields.io/badge/won\'t_be_fabricated-firebrick?style=for-the-badge&label=Release/fabrication%20result)
> Release vX.Y won't be fabricated, because ... .
>
> :exclamation: Browse [repository releases][repo_releases] for a better version.

---

![fix, not fabricated](https://img.shields.io/badge/fix%20(not%20fabricated)-indigo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)
> [Release vX.Y](/doc/releaselog.md#vX.Y) is a minor fix for vX.Y and was not fabricated at the time of release.
>
> :memo: Check the latest [release note of this version](https://github.com/VasilKalchev/LEDDs/releases/tag/vX.Y) for a possible update on the fabrication status.

</details>

-->

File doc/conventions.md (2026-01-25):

# Conventions

## Versioning
### Hardware (board)
Board releases are made with a major and a minor version (e.g. "LEDDs v1.2").

The major version is incremented when making incompatible changes to the board (e.g. pin rearrangement). The minor version is incremented for fixes or small additions that preserve compatibility with the firmware and the enclosure.

### Enclosure
The chassis and top plate's major versions correspond with the board's major version that they are compatible with.

The minor version is incremented for improvements.

Variants can be specified for different materials or cosmetic changes.
The chassis version must specify the material they are designed for, because of the different thread hole diameters.

### Examples:
#### Boards
`v1.0`: major version 1, minor version 0, original variant

#### Chassis
`v1.3-plastic`: compatible with all boards and plates versioned 1.Y, minor version 3, variant for FDM plastic (thread holes for inserts)
`v2.0-plastic`: compatible with all boards and plates versioned 2.Y, minor version 0, variant for SLA resin (thread holes direct screwing)

#### Top plates
`v3.1`: compatible with all boards and chassis versioned 3.Y, minor version 1, original variant
`v4.2-no_knob`: compatible with all boards and chassis versioned 4.Y, minor version 2, variant without knob cutout

## Development and release
### Before starting development
New board versions are developed in a separate branch.

### During development
Every change to the board is documented in [changelog.md](changelog.md).

### Before release
The [release_checklist.md](release_checklist.md) is completed.

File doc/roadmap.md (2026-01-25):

# Roadmap

This document outlines planned work for upcoming versions.
Items may change based on feedback and priorities.

## Next release (v3.0)
 - change MCU to ESP32-C3-WROOM-02
 - consolidate opto-isolators
 - remake whole case design in FreeCAD
 - match BOM to a distributor
 
## Short term

## Mid term

## Long term / ideas
 - smaller AC-DC converter

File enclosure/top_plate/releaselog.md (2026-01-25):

# Top plate release log
Fabrication results.

## v2.0 - 2025-04-02


> The fabricated top plate from version 2.0 works, but has some minor issues.
>
> :memo: Recommended for fabrication!

### Properties:
 - Fabricator: JLCPCB
 - Material: FR4 (Tg 135)
 - Layers: 2
 - PCB thickness: 1 mm
 - Solder mask color: white
 - Silkscreen: black
 - Surface finish: HASL (with lead)
 - Copper weight: 1 oz
 - Via covering: tented
 - Board outline tolerance: +-0.2 mm
 - Appearance quality: IPC Class 2 Standard
 - Silkscreen technology: Ink-jet/screen printing

### Problems
#### Minor
 - the holes around the knob cutout are too close to the edge
 - knob cutout is too wide

## v1.0 - 2025-02-17


> The fabricated top plate from version 1.0 works, but has some minor issues.
>
> :grey_exclamation: Obsolete.

### Properties:
 - Fabricator: JLCPCB
 - Material: FR4 (Tg 135)
 - Layers: 2
 - PCB thickness: 1 mm
 - Solder mask color: white
 - Silkscreen: black
 - Surface finish: HASL (with lead)
 - Copper weight: 1 oz
 - Via covering: tented
 - Board outline tolerance: +-0.2 mm
 - Appearance quality: IPC Class 2 Standard
 - Silkscreen technology: Ink-jet/screen printing

### Problems:
#### Minor
 - RST hole is too small
 - terminal screw holes are too small
 - it'll be better if the board can be rotated

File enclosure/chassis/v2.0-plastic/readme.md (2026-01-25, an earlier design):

[Tinkercad: LEDDs chassis v2.0 (plastic)](https://www.tinkercad.com/things/eWag09gYZm1-ledds-chassis-v20-plastic)

<div>
<p align="center">
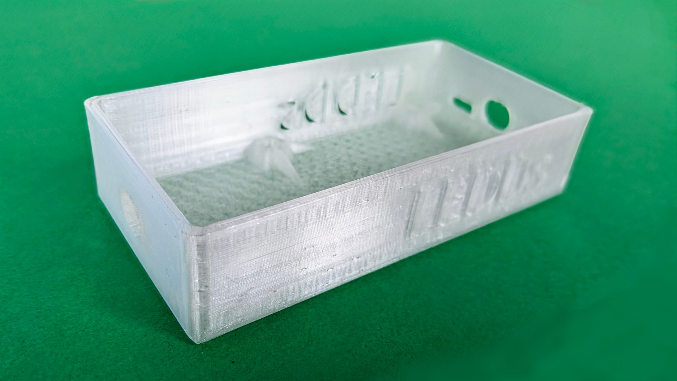
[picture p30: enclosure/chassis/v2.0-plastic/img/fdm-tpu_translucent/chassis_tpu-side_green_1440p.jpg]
chassis side
  
</p>
<p align="center">
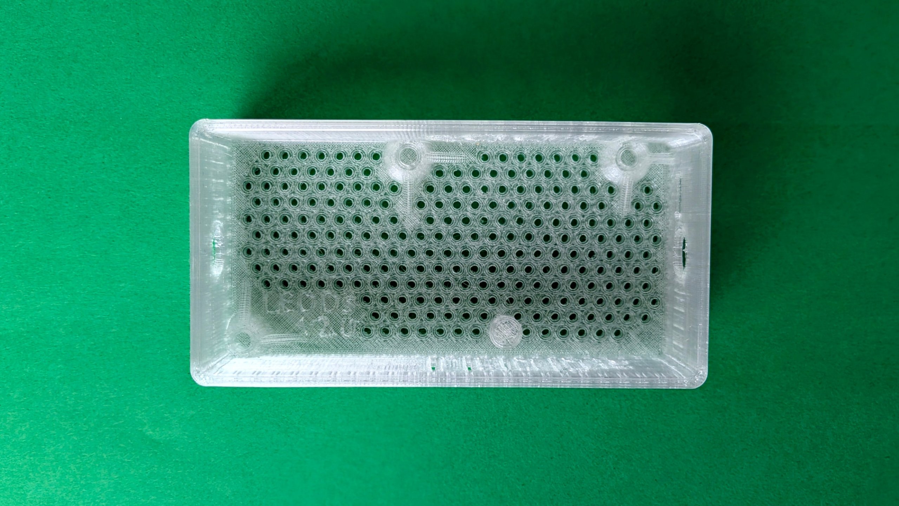
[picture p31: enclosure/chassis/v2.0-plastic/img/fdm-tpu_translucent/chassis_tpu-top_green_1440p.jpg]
chassis top
  
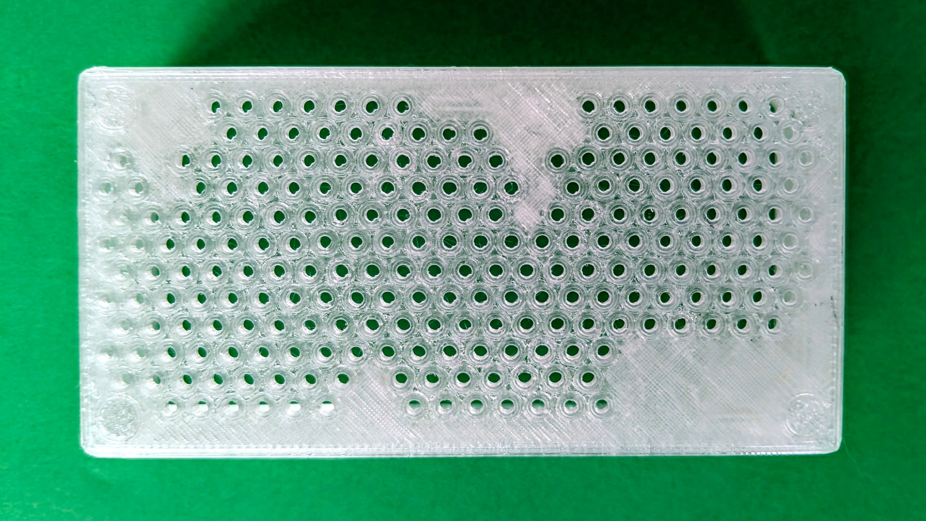
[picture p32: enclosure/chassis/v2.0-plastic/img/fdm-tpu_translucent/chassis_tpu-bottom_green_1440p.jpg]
chassis bottom
  
</p>
</div>

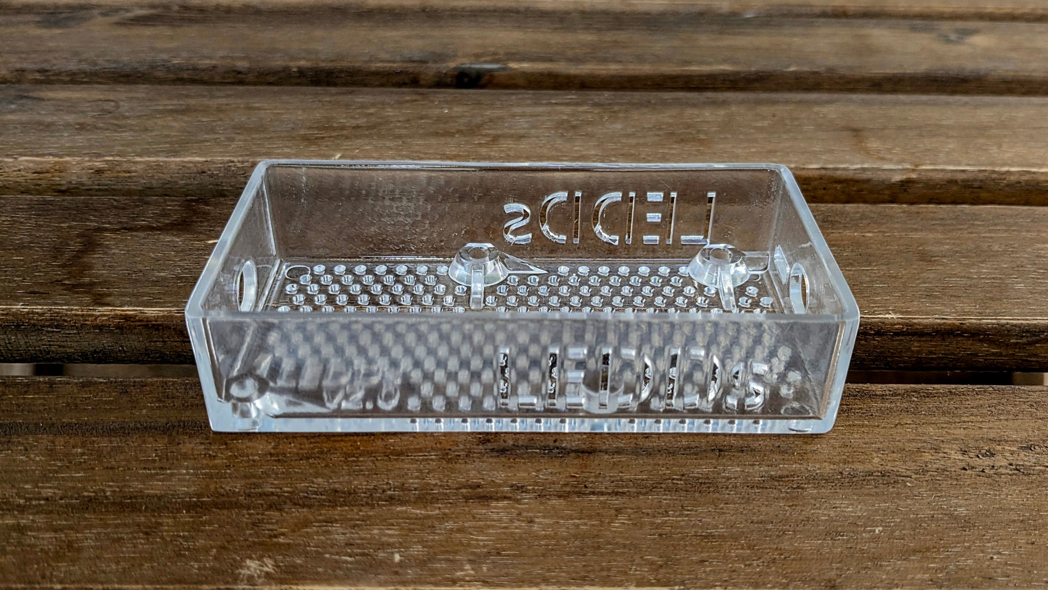
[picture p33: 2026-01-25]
enclosure/chassis/v2.0-resin/img/sla-8001_transparent/chassis_resin-front_1440p.jpg

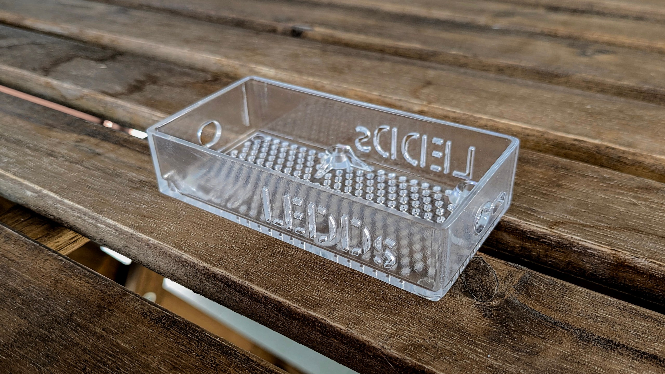
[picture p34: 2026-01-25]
enclosure/chassis/v2.0-resin/img/sla-8001_transparent/chassis_resin-side_right_1440p.jpg

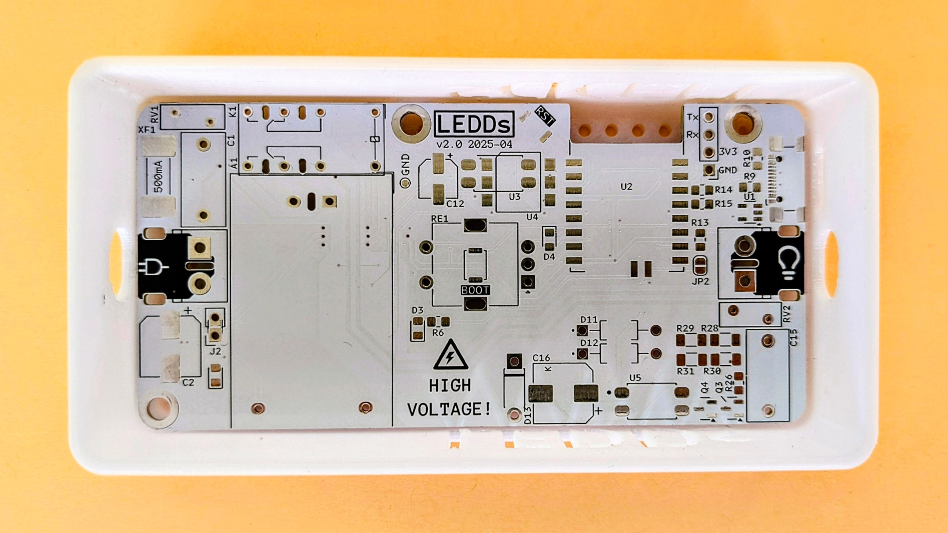
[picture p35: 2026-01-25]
enclosure/chassis/v2.1-plastic/img/fdm-abs_white/chassis_white-pcb-top_1440p.jpg

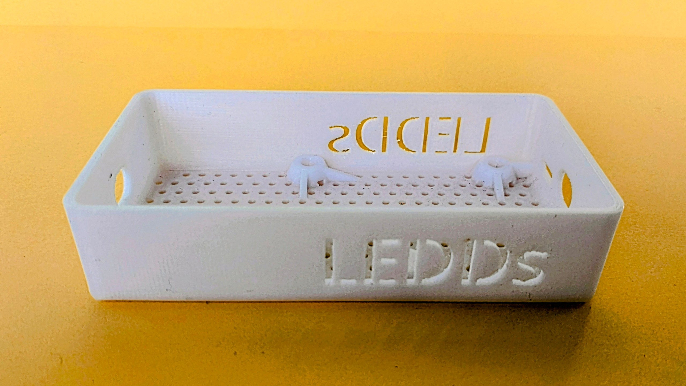
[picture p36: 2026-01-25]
enclosure/chassis/v2.1-plastic/img/fdm-abs_white/chassis_white-front_angle_1440p.jpg

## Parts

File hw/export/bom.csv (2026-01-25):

Reference | Value | Footprint | Description | Qty | DNP
A1 | HLK-PM03 | Converter_ACDC:Converter_ACDC_Hi-Link_HLK-PMxx |  | 1
C1,C3,C4,C5,C6,C10,C13,C14,C15 | 100n | Capacitor_SMD:C_0805_2012Metric_Pad1.18x1.45mm_HandSolder,Capacitor_THT:C_Rect_L13.0mm_W6.0mm_P10.00mm_FKS3_FKP3_MKS4 |  | 9
C2 | 220u | Capacitor_SMD:CP_Elec_8x6.5 |  | 1
C7,C8,C9 | 1u | Capacitor_SMD:C_0805_2012Metric_Pad1.18x1.45mm_HandSolder | Unpolarized capacitor, small symbol | 3
C11 | 4.7n | Capacitor_SMD:C_1206_3216Metric_Pad1.33x1.80mm_HandSolder |  | 1
C12 | 10u | Capacitor_SMD:CP_Elec_5x5.7 |  | 1
C16 | 330u | Capacitor_SMD:CP_Elec_8x10 |  | 1
D1 | white | LED_SMD:LED_0805_2012Metric_Pad1.15x1.40mm_HandSolder |  | 1
D2,D6,D7,D8,D9,D10 | 1N4148W | Diode_SMD:D_SOD-123 |  | 6
D3 | red | LED_SMD:LED_0805_2012Metric_Pad1.15x1.40mm_HandSolder |  | 1
D4 | blue | LED_SMD:LED_0805_2012Metric_Pad1.15x1.40mm_HandSolder |  | 1
D5,SW1,SW2 | ~ | Button_Switch_SMD:SW_Push_SPST_NO_Alps_SKRK,LED_SMD:LED_0805_2012Metric_Pad1.15x1.40mm_HandSolder | Push button switch, generic, two pins | 3
D11,D12 | UF4004 | UF4004:DIOAD1055W87L533D272 |  | 2
D13 | BZV55C15 | Diode_THT:D_DO-41_SOD81_P7.62mm_Horizontal |  | 1
H1,H2,H3 | 20mm | MountingHole:MountingHole_3.2mm_M3_DIN965_Pad_TopBottom | M3x20mm | 3
J1,J5 | Screw_Terminal_01x02 | TerminalBlock:TerminalBlock_bornier-2_P5.08mm |  | 2
J2 | Conn_01x02_Pin | Connector_PinSocket_2.54mm:PinSocket_1x02_P2.54mm_Vertical | Generic connector, single row, 01x02, script generated | 1
J3 | USB_C_Receptacle_USB2.0_14P | Connector_USB:USB_C_Receptacle_GCT_USB4110 | USB 2.0-only 14P Type-C Receptacle connector | 1
J4 | Conn_01x06 | Connector_PinHeader_2.54mm:PinHeader_1x04_P2.54mm_Vertical | Generic connector, single row, 01x04, script generated (kicad-library-utils/schlib/autogen/connector/) | 1
K1 | Relay_DPDT | Relay:HK19F |  | 1
KN1 | 20 mm |  | Knob: 20 mm | 1
Q1,Q2,Q3 | MMBT3904 | Package_TO_SOT_SMD:SOT-23 | 0.2A Ic, 40V Vce, Small Signal NPN Transistor, SOT-23 | 3
Q4 | MMBT3906 | Package_TO_SOT_SMD:SOT-23 | -0.2A Ic, -40V Vce, Small Signal PNP Transistor, SOT-23 | 1
Q5,Q6 | IPN80R900P7 | Package_TO_SOT_SMD:SOT-223-3_TabPin2 | N-MOSFET transistor, gate/drain/source | 2
R1,R2 | 330 | Resistor_SMD:R_0805_2012Metric_Pad1.20x1.40mm_HandSolder |  | 2
R3,R4,R5,R11,R12,R13,R23,R25,R28,R29,R30,R31 | 20k | Resistor_SMD:R_0805_2012Metric_Pad1.20x1.40mm_HandSolder,Resistor_SMD:R_1206_3216Metric_Pad1.30x1.75mm_HandSolder |  | 12
R6,R8,R22 | 240 | Resistor_SMD:R_0805_2012Metric_Pad1.20x1.40mm_HandSolder |  | 3
R7 | 120 | Resistor_SMD:R_0805_2012Metric_Pad1.20x1.40mm_HandSolder |  | 1
R9,R10 | 5k1 | Resistor_SMD:R_0805_2012Metric_Pad1.20x1.40mm_HandSolder | Resistor, small symbol | 2
R14,R15 | 0 | Resistor_SMD:R_0805_2012Metric_Pad1.20x1.40mm_HandSolder |  | 2
R16,R17,R18,R19 | 91k | Resistor_SMD:R_1206_3216Metric_Pad1.30x1.75mm_HandSolder |  | 4
R20 | 56k | Resistor_SMD:R_0805_2012Metric_Pad1.20x1.40mm_HandSolder |  | 1
R21 | 100k | Resistor_SMD:R_0805_2012Metric_Pad1.20x1.40mm_HandSolder |  | 1
R24,R26 | 30 | Resistor_SMD:R_0805_2012Metric_Pad1.20x1.40mm_HandSolder |  | 2
R27 | 220 | Resistor_SMD:R_1206_3216Metric_Pad1.30x1.75mm_HandSolder |  | 1
RE1 | RotaryEncoder_Switch | Rotary_Encoder:RotaryEncoder_Alps_EC11E-Switch_Vertical_H20mm |  | 1
RV1,RV2 | 275V | Varistor:RV_Disc_D9mm_W3.5mm_P5mm |  | 2
SP1,SP2,SP3 | 15mm |  | Spacer: M3x15mm | 3
TI1,TI2,TI3 | 4x4.2 mm |  | Threaded insert: M3 x L4 x OD4.2 mm | 3
U1 | AP2112K-3.3 | Package_TO_SOT_SMD:SOT-23-5 | 600mA low dropout linear regulator, with enable pin, 3.8V-6V input voltage range, 3.3V fixed positive output, SOT-23-5 | 1
U2 | ESP32-C3-12F | ESP32-C3-12F_RFS |  | 1
U3,U5 | PC817XI | PC817XI:SOIC254P975X460-4N |  | 2
U4 | H11L1SR2M | H11L1SR2M:IC_H11L1SR2M |  | 1
XF1 | 500mA | Fuse:Fuse_Schurter_UMZ250 | Fuse, small symbol | 1

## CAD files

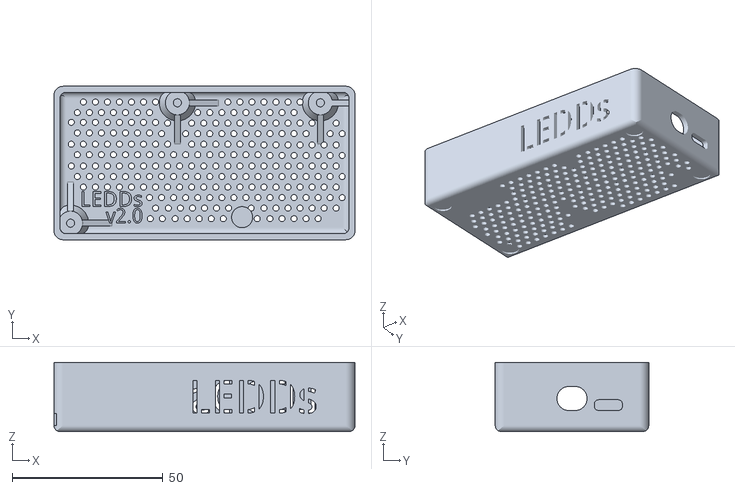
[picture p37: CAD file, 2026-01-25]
enclosure/chassis/v2.0-resin/LEDDs chassis v2.0 (resin).stl
100.0 x 51.0 x 23.0

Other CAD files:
enclosure/chassis/v2.1-plastic/LEDDs chassis v2.1 (plastic).stl
enclosure/chassis/v2.0-plastic/LEDDs chassis v2.0 (plastic).stl

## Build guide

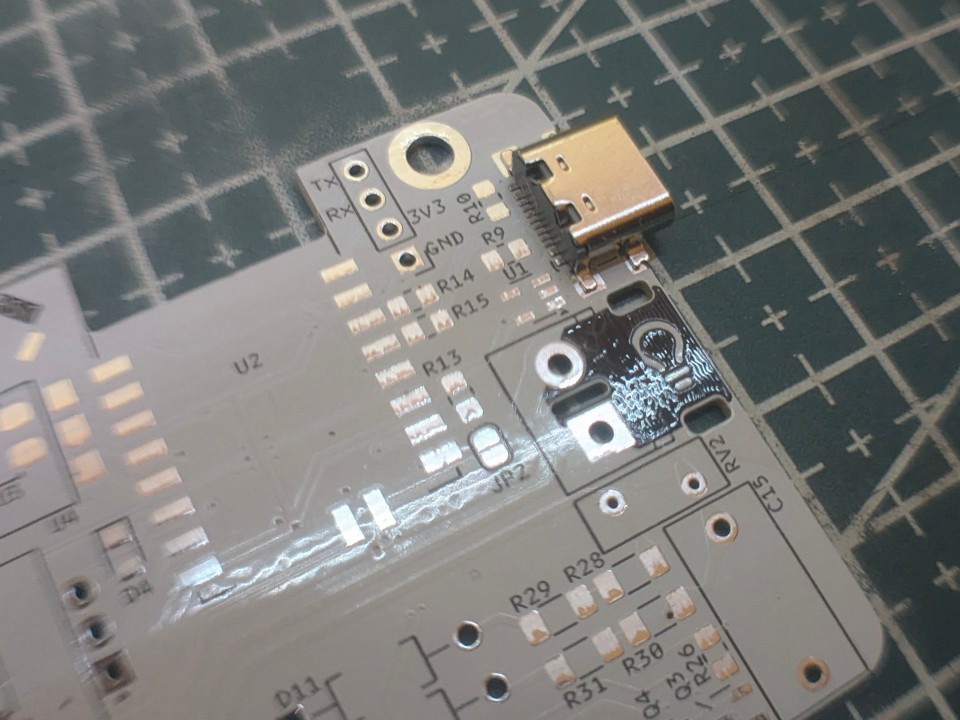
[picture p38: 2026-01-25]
doc/assets/assembly/usb-720p.jpg

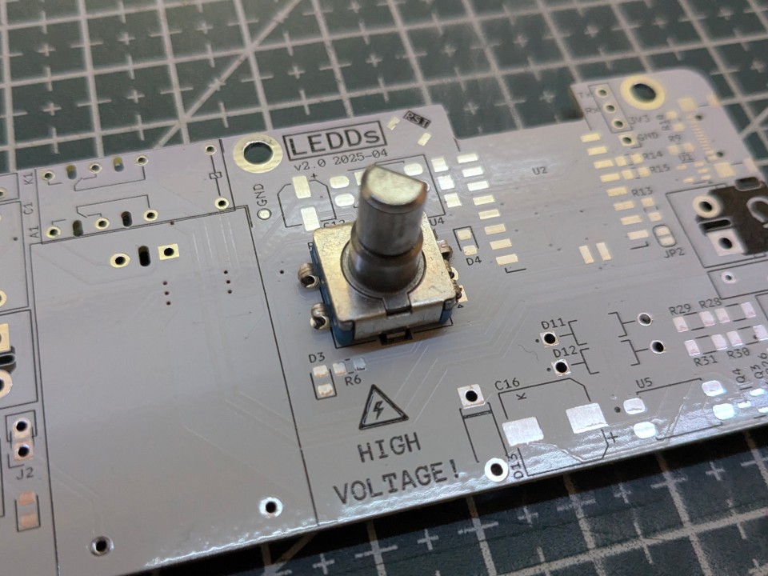
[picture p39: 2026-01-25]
doc/assets/assembly/rotary_encoder-720p.jpg

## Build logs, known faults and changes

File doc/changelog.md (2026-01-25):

# Change log

## v2.0 - 2025-04-02
Changed the MCU to ESP32-C3. Added an USB-C port.

### Added
 - USB-C receptacle for programming the MCU
 - 3.3 V linear regulator
 - bridged solder jumper and header, separating 3.3 V (for current measuring)
 - LED on the bottom of the board

### Changed
 - MCU module from ESP-12 to ESP32-C3-C12
 - moved the top-right screw hole to make space for the USB-C receptacle
 - zero-cross rectification resistors values to 91 kΩ
 - widened zip-tie holes
 - adjusted cutout holes dimensions
 - increased some silkscreen text sizes

### Removed
 - UART's CTS and DTR pins from the header
 - UART's auto enter programming circuit
 - test points for 3.3 V, analog input and GPIO4

<!-- template

## vX.Y-type - 202Y-MM-DD
Comment...

### Schematic/Board
#### Added
 - ... (#<issue>)
 -

#### Fixed
 -
 -

#### Changed
 -
 -

#### Removed
 -
 -

-->

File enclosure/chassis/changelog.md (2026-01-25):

# Chassis change log

## v2.1 - 2025-04-20
Visual improvements.

### Changed
 - increased all fillet radii to 3 mm
 - changed the bottom holes distances to be more regular
 - moved the thread supports to avoid covering the holes
 - increased USB cutout's size
 - moved the name and version to the outside bottom as deboss

## v2.0 - 2025-04-03
Added hole for the USB-C port, visual and minor functional improvements.

### Added
 - name cutout on the back side
 - holes on the bottom
 - cutout for the USB-C receptacle
 - deboss for rubber legs

### Changed
 - moved the name cutout to the right
 - wire cutouts from rectangle to ellipse
 - moved the top-right thread insert hole to match the PCB and the top plate

### Removed
 - cutouts for the UART header and the antenna

<!-- template

## vX.Y-type - 202Y-MM-DD
Comment...

### Added
 - ... (#<issue>)
 -

### Fixed
 -
 -

### Changed
 -
 -

### Removed
 -
 -

-->

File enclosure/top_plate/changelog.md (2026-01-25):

# Top plate change log

## v2.0 - 2025-04-20
Made the text on the top plate barely visible and rotated by 90 degrees, so that the enclosure can be rotated without appearing upside down.

### Added
 - added holes around the knob
 - text on the bottom side

### Changed
 - increased width of copper frame from 1 mm to 2 mm
 - rotated board name
 - all text from exposed copper to copper knockout (less visible)
 - widened the knob cutout by 0.2 mm
 - moved the top-right screw hole to match the PCB
 - screw holes from board outlines to footprints of mounting holes

### Removed
 - holes for the LED, screw terminals and reset button

<!-- template

## vX.Y-type - 202Y-MM-DD
Comment...

### Added
 - ... (#<issue>)
 -

### Fixed
 -
 -

### Changed
 -
 -

### Removed
 -
 -

-->

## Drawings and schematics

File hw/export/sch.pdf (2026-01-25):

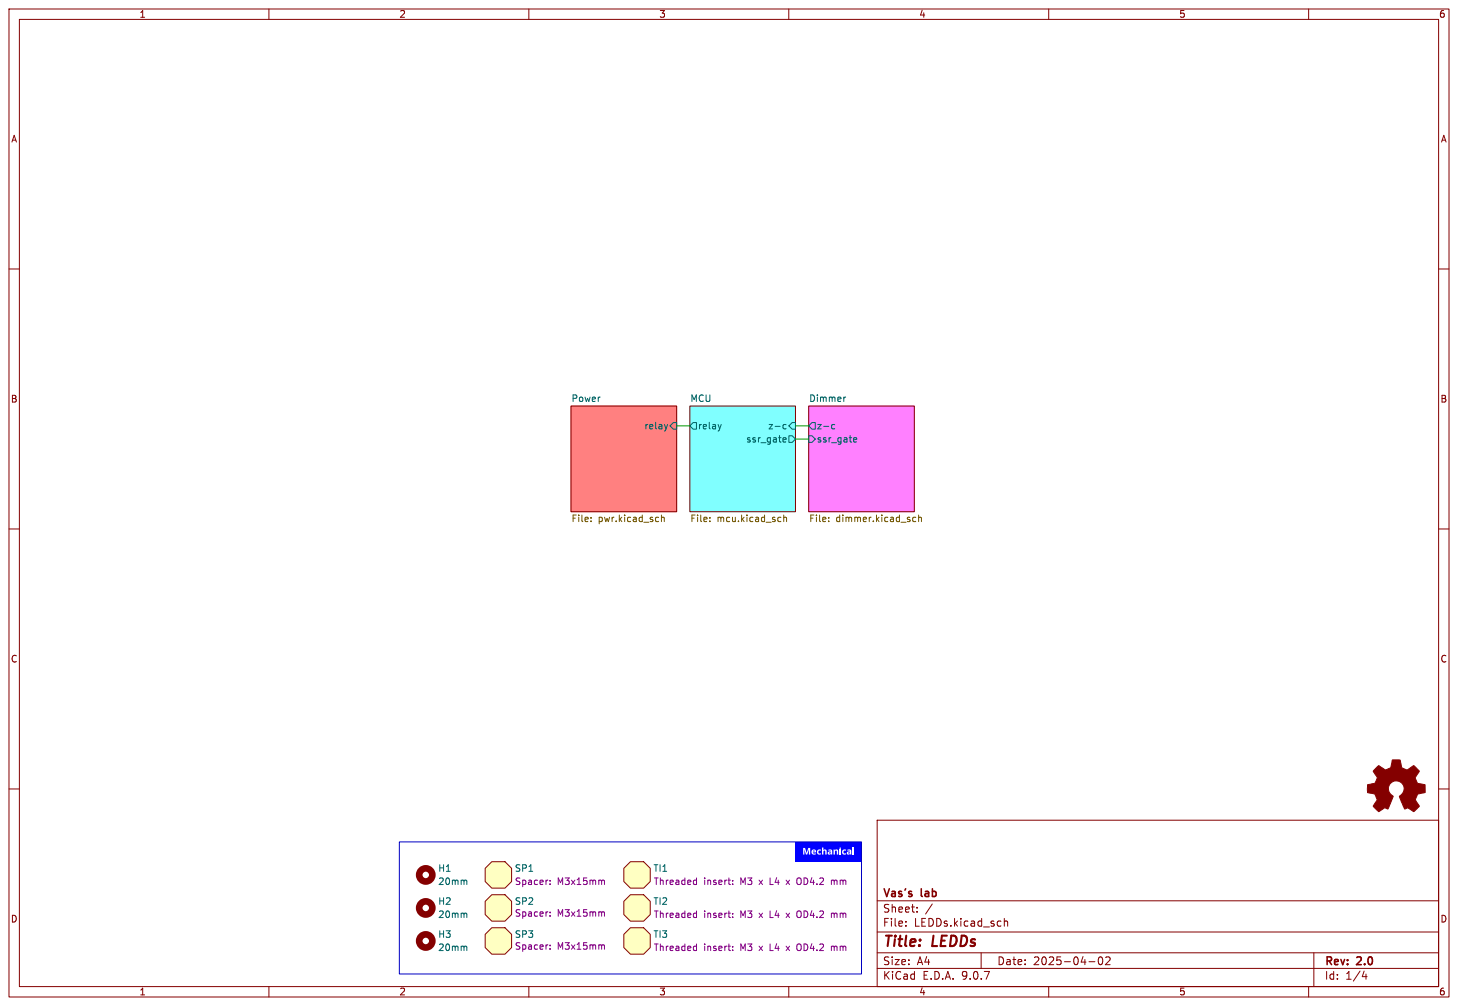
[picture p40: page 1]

relay Power File: pwr.kicad_sch H2

File: LEDDs.kicad_sch Sheet: / Vas's lab

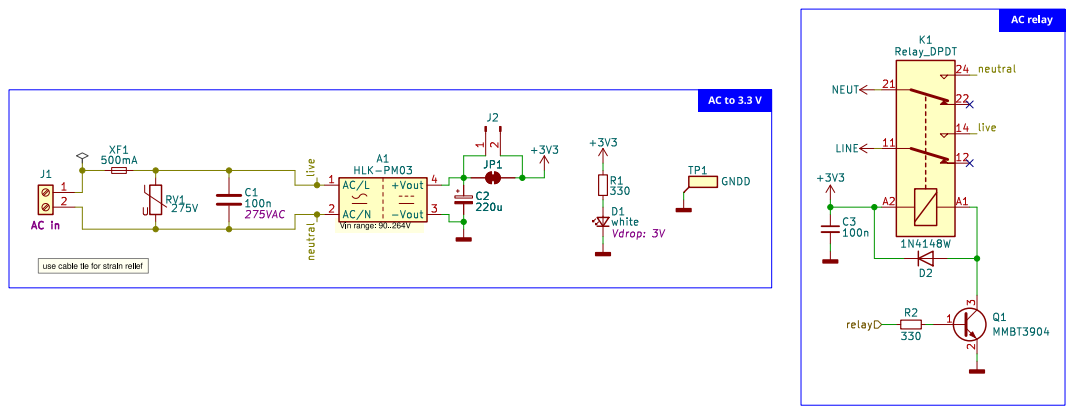
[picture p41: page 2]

Id: 2/4 Title: Power File: pwr.kicad_sch Sheet: /Power/ Vas's lab C1
275VAC

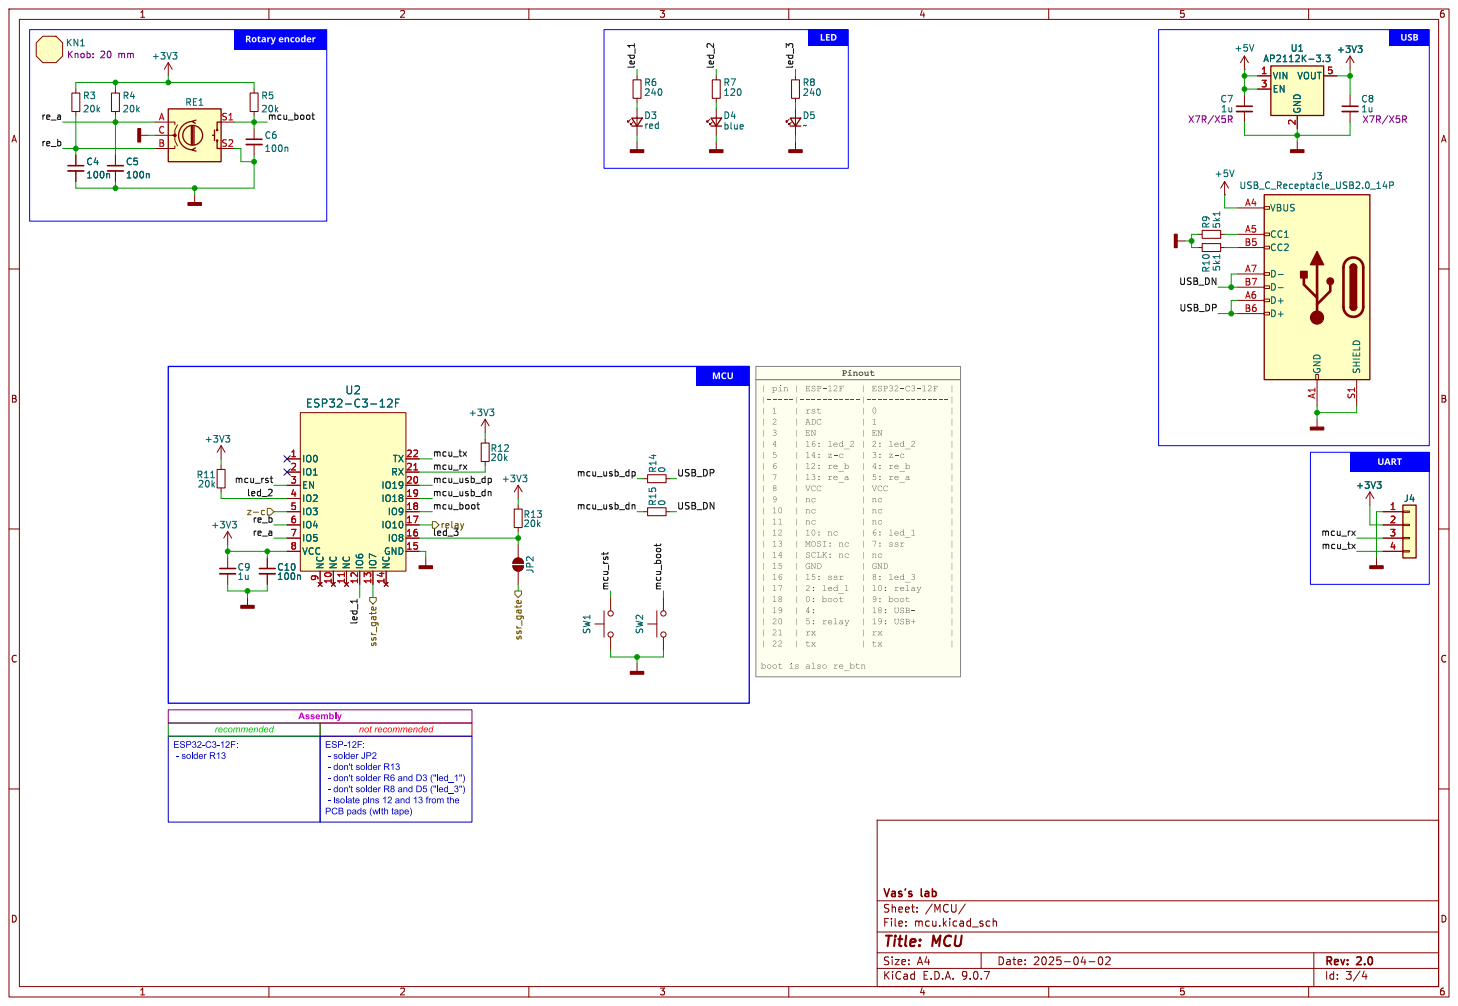
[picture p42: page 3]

File: mcu.kicad_sch Sheet: /MCU/ Vas's lab

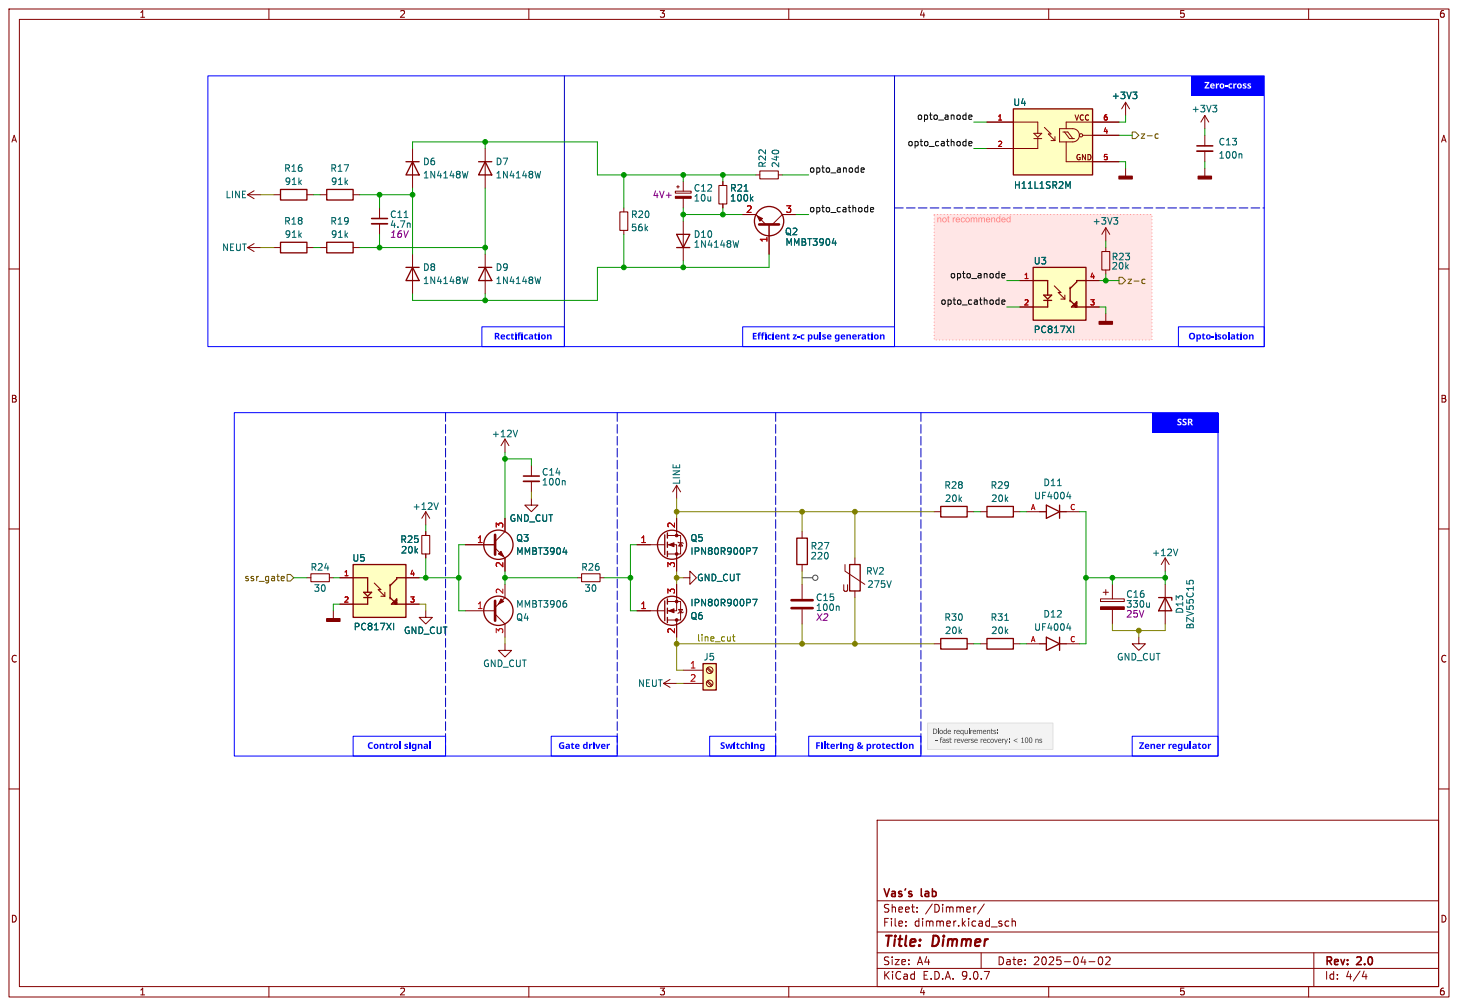
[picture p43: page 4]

Id: 4/4 Title: Dimmer File: dimmer.kicad_sch Sheet: /Dimmer/ Vas's lab R27

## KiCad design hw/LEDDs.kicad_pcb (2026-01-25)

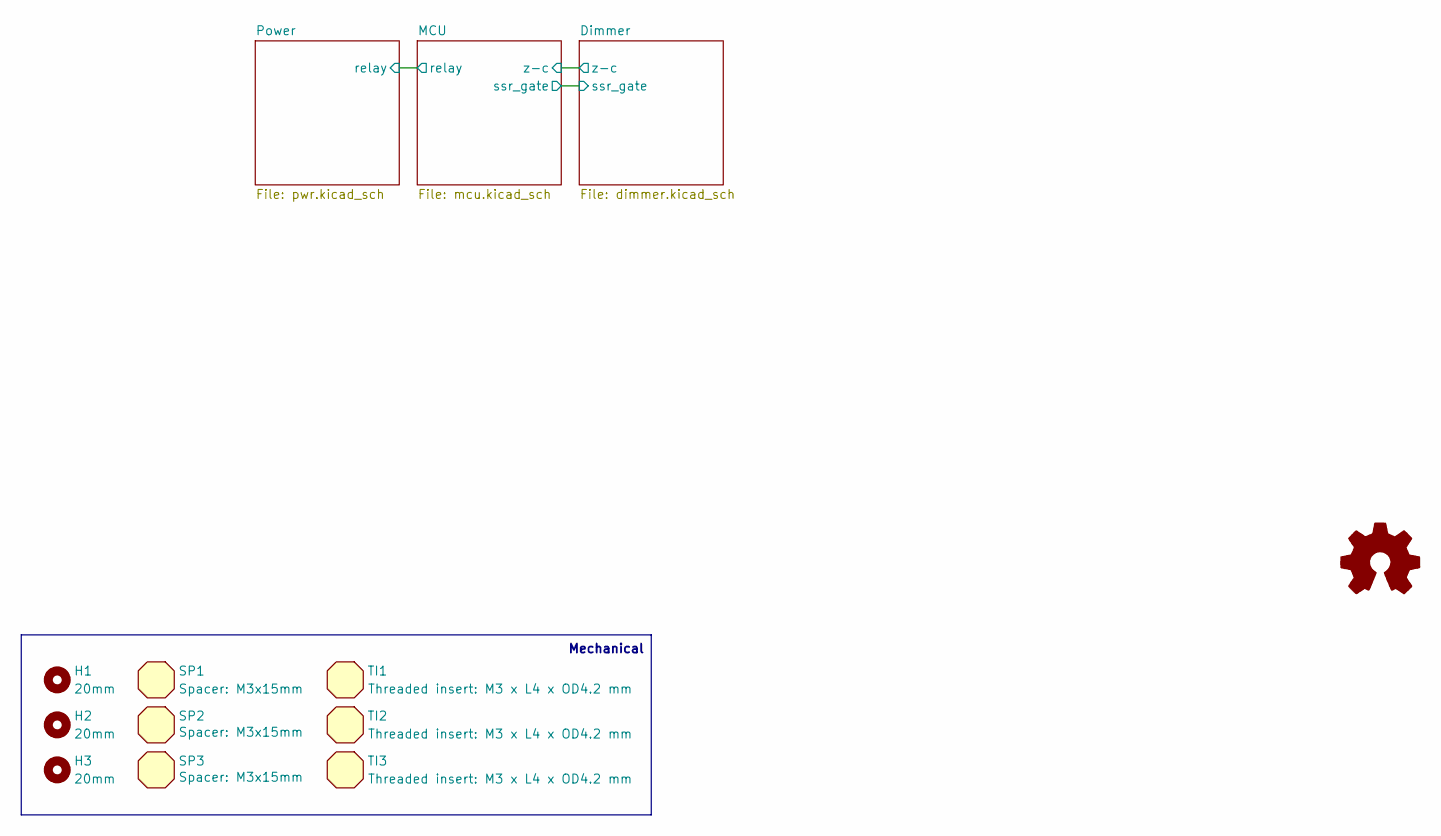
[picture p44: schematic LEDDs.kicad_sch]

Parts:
H1, H2, H3: 20mm; MountingHole_3.2mm_M3_DIN965_Pad_TopBottom
SP1, SP2, SP3: 15mm
TI1, TI2, TI3: 4x4.2 mm

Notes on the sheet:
Mechanical

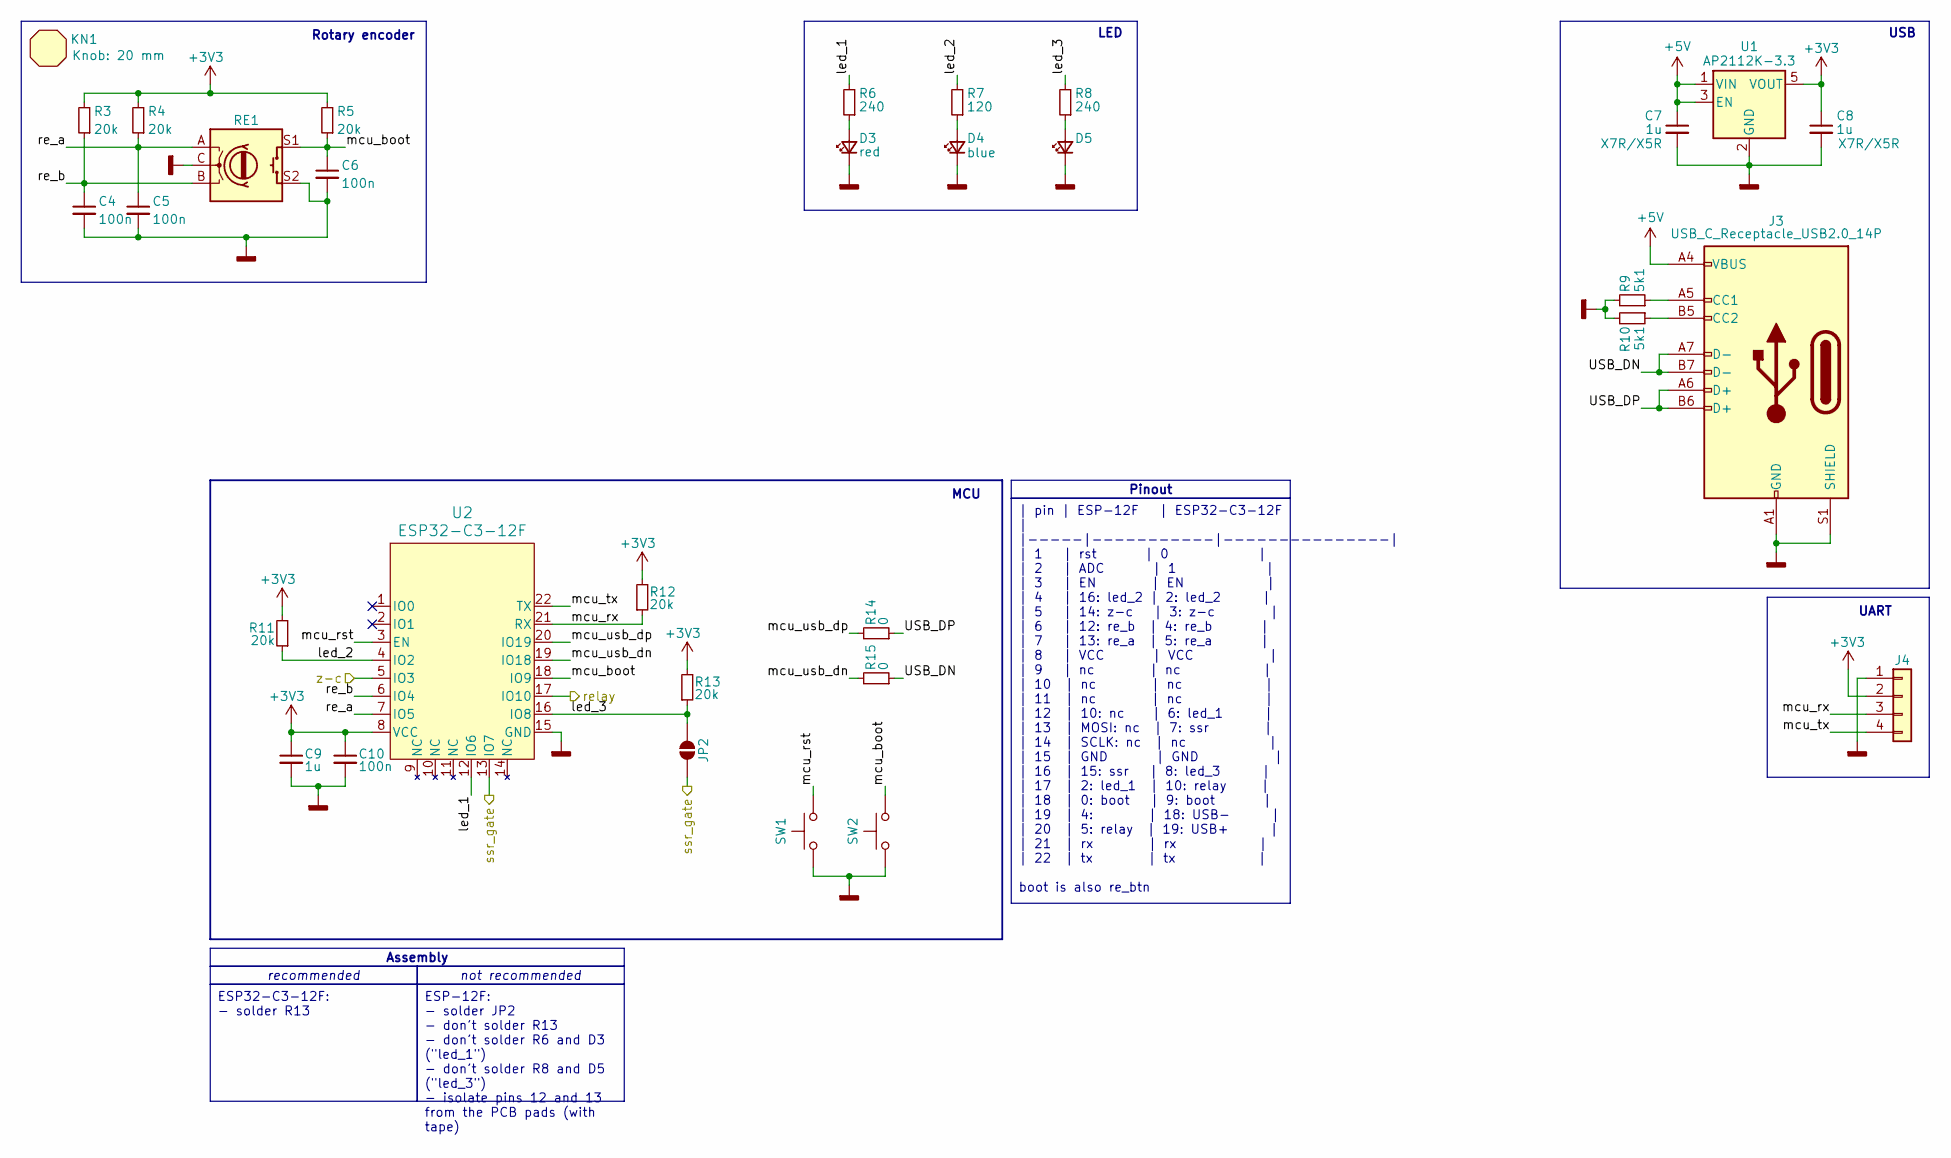
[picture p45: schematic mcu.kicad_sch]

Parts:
C4, C5, C6, C10: 100n; C_0805_2012Metric_Pad1.18x1.45mm_HandSolder
C7, C8, C9: 1u; C_0805_2012Metric_Pad1.18x1.45mm_HandSolder
D3: red; LED_0805_2012Metric_Pad1.15x1.40mm_HandSolder
D4: blue; LED_0805_2012Metric_Pad1.15x1.40mm_HandSolder
D5: LED_0805_2012Metric_Pad1.15x1.40mm_HandSolder
J3: USB_C_Receptacle_USB2.0_14P; USB_C_Receptacle_GCT_USB4110
J4: Conn_01x06; PinHeader_1x04_P2.54mm_Vertical
JP2: SolderJumper_2_Open; SolderJumper-2_P1.3mm_Open_RoundedPad1.0x1.5mm
KN1: 20 mm
R3, R4, R5, R11, R12, R13: 20k; R_0805_2012Metric_Pad1.20x1.40mm_HandSolder
R6, R8: 240; R_0805_2012Metric_Pad1.20x1.40mm_HandSolder
R7: 120; R_0805_2012Metric_Pad1.20x1.40mm_HandSolder
R9, R10: 5k1; R_0805_2012Metric_Pad1.20x1.40mm_HandSolder
R14, R15: 0; R_0805_2012Metric_Pad1.20x1.40mm_HandSolder
RE1: RotaryEncoder_Switch; RotaryEncoder_Alps_EC11E-Switch_Vertical_H20mm
SW1, SW2: SW_Push_SPST_NO_Alps_SKRK
U1: AP2112K-3.3; SOT-23-5
U2: ESP32-C3-12F; ESP32-C3-12F_RFS

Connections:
+3V3: C8.1, C9.1, C10.1, J4.2, R3.2, R4.2, R5.2, R11.2, R12.2, R13.2, U1.5 (VOUT), U2.8 (VCC); also elsewhere on the board
+5V: C7.1, J3.A4 (VBUS), J3.A9 (VBUS), J3.B4 (VBUS), J3.B9 (VBUS), U1.1 (VIN), U1.3 (EN)
/Dimmer/ssr_gate: JP2.2 (B), U2.13 (IO7); also elsewhere on the board
/Dimmer/z-c: U2.5 (IO3); also elsewhere on the board
/MCU/USB_DN: J3.A7 (D-), J3.B7 (D-), R15.1
/MCU/USB_DP: J3.A6 (D+), J3.B6 (D+), R14.1
/MCU/led_1: R6.2, U2.12 (IO6)
/MCU/led_2: R7.2, R11.1, U2.4 (IO2)
/MCU/led_3: JP2.1 (A), R8.2, R13.1, U2.16 (IO8)
/MCU/mcu_boot: C6.1, R5.1, RE1.S1, SW2.2, U2.18 (IO9)
/MCU/mcu_rst: SW1.2, U2.3 (EN)
/MCU/mcu_rx: J4.3, R12.1, U2.21 (RX)
/MCU/mcu_tx: J4.4, U2.22 (TX)
/MCU/mcu_usb_dn: R15.2, U2.19 (IO18)
/MCU/mcu_usb_dp: R14.2, U2.20 (IO19)
/MCU/re_a: C5.1, R4.1, RE1.A, U2.7 (IO5)
/MCU/re_b: C4.1, R3.1, RE1.B, U2.6 (IO4)
/MCU/relay: U2.17 (IO10); also elsewhere on the board
GNDD: C4.2, C5.2, C6.2, C7.2, C8.2, C9.2, C10.2, D3.1 (K), D4.1 (K), D5.1 (K), J3.A1 (GND), J3.A12 (GND), J3.B1 (GND), J3.B12 (GND), J3.S1 (SHIELD), J4.1, R9.2, R10.2, RE1.C, RE1.S2, SW1.1, SW2.1, U1.2 (GND), U2.15 (GND); also elsewhere on the board
unnamed: D3.2 (A), R6.1
unnamed: D4.2 (A), R7.1
unnamed: D5.2 (A), R8.1
unnamed: J3.A5 (CC1), R9.1
unnamed: J3.B5 (CC2), R10.1

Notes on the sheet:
MCU
Pinout
ESP32-C3-12F: - solder R13
| pin | ESP-12F | ESP32-C3-12F | |-----|-----------|---------------| | 1 | rst | 0 | | 2 | ADC | 1 | | 3 | EN | EN | | 4 | 16: led_2 | 2: led_2 | | 5 | 14: z-c | 3: z-c | | 6 | 12: re_b | 4: re_b | | 7 | 13: re_a | 5: re_a | | 8 | VCC | VCC | | 9 | nc | nc | | 10 | nc | nc | | 11 | nc | nc | | 12 |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
USB
Rotary encoder
recommended
Assembly
not recommended
ESP-12F: - solder JP2 - don't solder R13 - don't solder R6 and D3 ("led_1") - don't solder R8 and D5 ("led_3") - isolate pins 12 and 13 from the PCB pads (with tape)
LED
UART

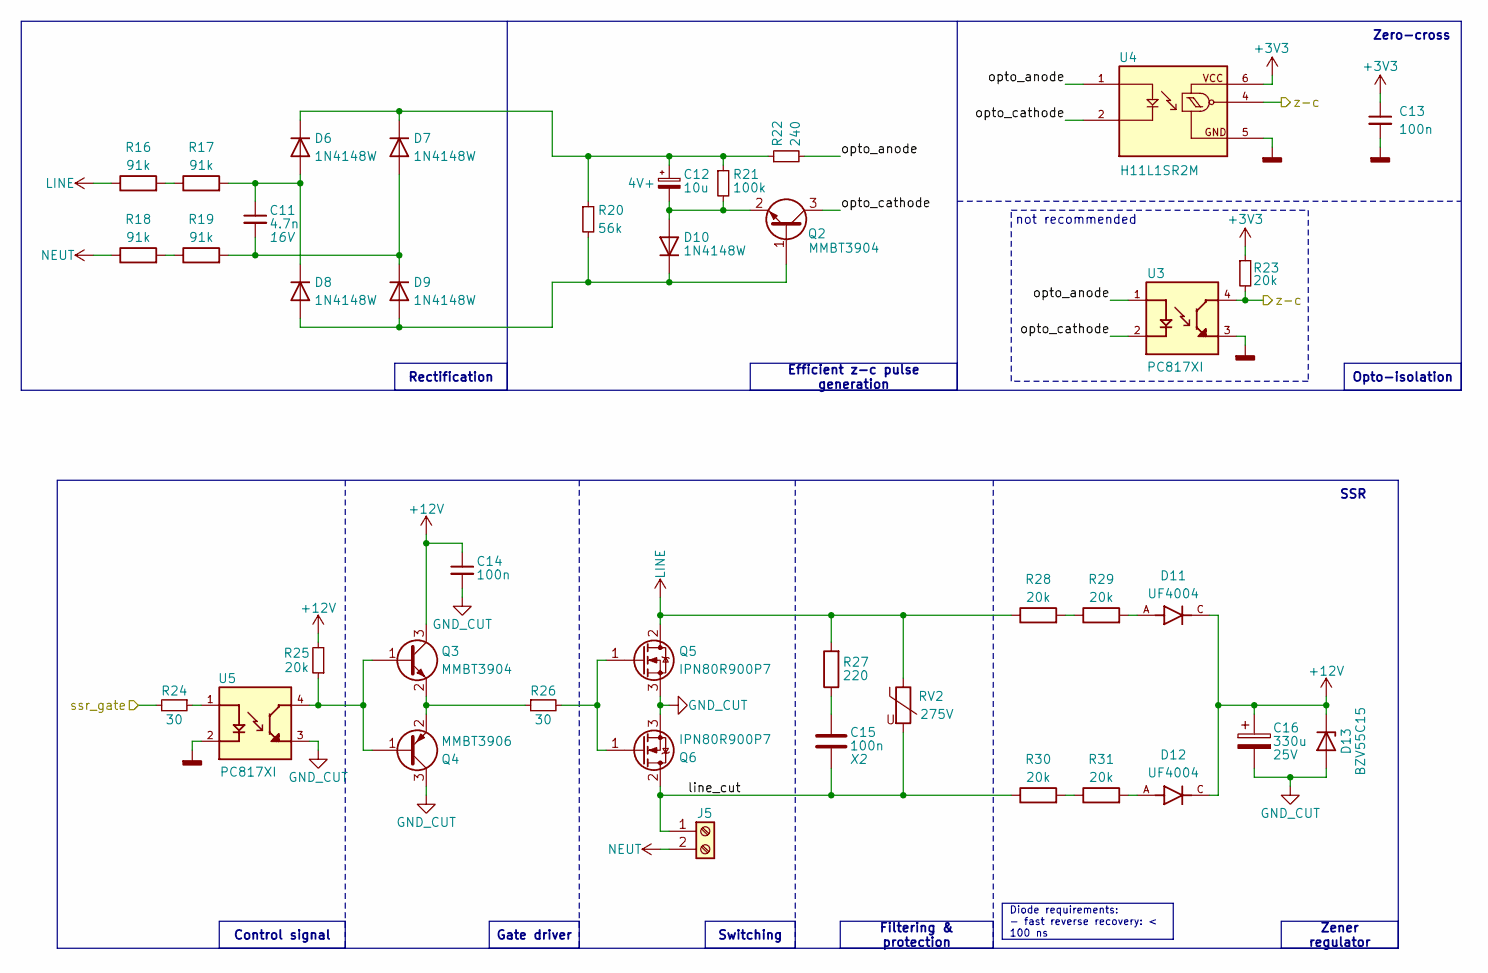
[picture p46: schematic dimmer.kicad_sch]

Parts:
C11: 4.7n; C_1206_3216Metric_Pad1.33x1.80mm_HandSolder
C12: 10u; CP_Elec_5x5.7
C13, C14: 100n; C_0805_2012Metric_Pad1.18x1.45mm_HandSolder
C15: 100n; C_Rect_L13.0mm_W6.0mm_P10.00mm_FKS3_FKP3_MKS4
C16: 330u; CP_Elec_8x10
D6, D7, D8, D9, D10: 1N4148W; D_SOD-123
D11, D12: UF4004; DIOAD1055W87L533D272; PARTREV N/A
D13: BZV55C15; D_DO-41_SOD81_P7.62mm_Horizontal
J5: Screw_Terminal_01x02; TerminalBlock_bornier-2_P5.08mm
Q2, Q3: MMBT3904; SOT-23
Q4: MMBT3906; SOT-23
Q5, Q6: IPN80R900P7; SOT-223-3_TabPin2
R16, R17, R18, R19: 91k; R_1206_3216Metric_Pad1.30x1.75mm_HandSolder
R20: 56k; R_0805_2012Metric_Pad1.20x1.40mm_HandSolder
R21: 100k; R_0805_2012Metric_Pad1.20x1.40mm_HandSolder
R22: 240; R_0805_2012Metric_Pad1.20x1.40mm_HandSolder
R23, R25: 20k; R_0805_2012Metric_Pad1.20x1.40mm_HandSolder
R24, R26: 30; R_0805_2012Metric_Pad1.20x1.40mm_HandSolder
R27: 220; R_1206_3216Metric_Pad1.30x1.75mm_HandSolder
R28, R29, R30, R31: 20k; R_1206_3216Metric_Pad1.30x1.75mm_HandSolder
RV2: 275V; RV_Disc_D9mm_W3.5mm_P5mm
U3, U5: PC817XI; SOIC254P975X460-4N
U4: H11L1SR2M; IC_H11L1SR2M; PARTREV 3

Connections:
+3V3: C13.1, R23.1, U4.6; also elsewhere on the board
+12V: C14.1, C16.1, D11.C, D12.C, D13.1 (K), Q3.3 (C), R25.2
/Dimmer/line_cut: C15.2, J5.1, Q6.2 (D), R30.1, RV2.2
/Dimmer/opto_anode: R22.2, U3.1, U4.1
/Dimmer/opto_cathode: Q2.3 (C), U3.2, U4.2
/Dimmer/ssr_gate: R24.2; also elsewhere on the board
/Dimmer/z-c: R23.2, U3.4, U4.4; also elsewhere on the board
GNDD: C13.2, U3.3, U4.5, U5.2; also elsewhere on the board
GND_CUT: C14.2, C16.2, D13.2 (A), Q4.3 (C), Q5.3 (S), Q6.3 (S), U5.3
LINE: Q5.2 (D), R16.1, R27.2, R28.1, RV2.1; also elsewhere on the board
NEUT: J5.2, R18.1; also elsewhere on the board
unnamed: C15.1, R27.1
unnamed: C11.1, D6.2 (A), D8.1 (K), R17.2
unnamed: C12.1, D6.1 (K), D7.1 (K), R20.1, R21.1, R22.1
unnamed: C11.2, D7.2 (A), D9.1 (K), R19.2
unnamed: C12.2, D10.2 (A), Q2.2 (E), R21.2
unnamed: D8.2 (A), D9.2 (A), D10.1 (K), Q2.1 (B), R20.2
unnamed: D11.A, R29.2
unnamed: D12.A, R31.2
unnamed: Q3.1 (B), Q4.1 (B), R25.1, U5.4
unnamed: Q3.2 (E), Q4.2 (E), R26.1
unnamed: Q5.1 (G), Q6.1 (G), R26.2
unnamed: R16.2, R17.1
unnamed: R18.2, R19.1
unnamed: R24.1, U5.1
unnamed: R28.2, R29.1
unnamed: R30.2, R31.1

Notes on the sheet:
not recommended
Control signal
Filtering & protection
SSR
Switching
Diode requirements: - fast reverse recovery: < 100 ns
Rectification
Efficient z-c pulse generation
Gate driver
Zener regulator
Opto-isolation
Zero-cross

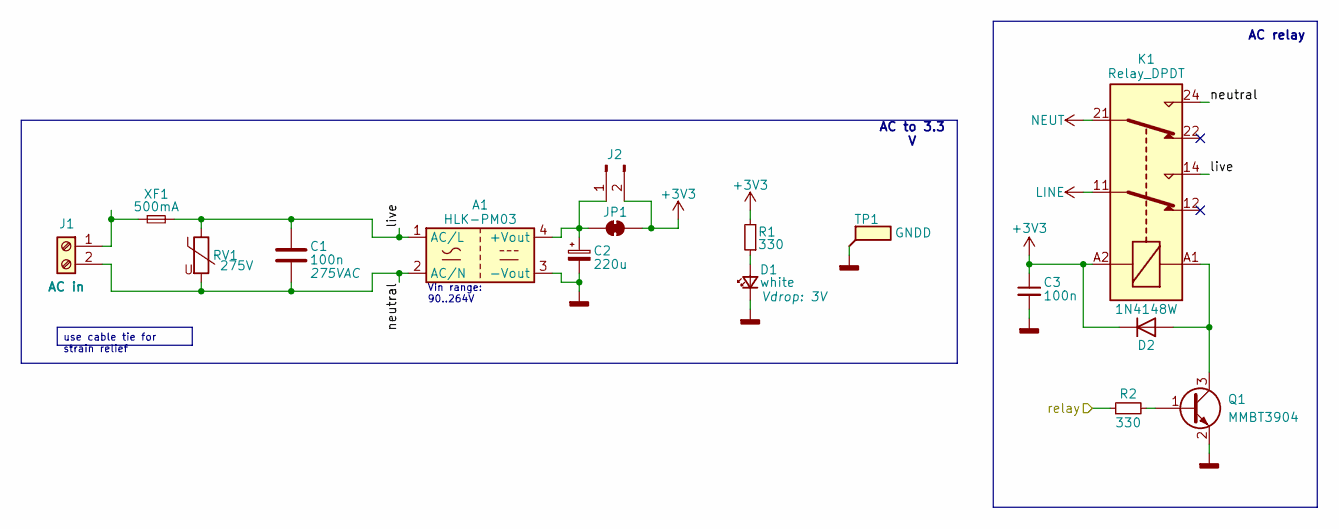
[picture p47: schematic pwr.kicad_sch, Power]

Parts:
A1: HLK-PM03; Converter_ACDC_Hi-Link_HLK-PMxx
C1: 100n; C_Rect_L13.0mm_W6.0mm_P10.00mm_FKS3_FKP3_MKS4
C2: 220u; CP_Elec_8x6.5
C3: 100n; C_0805_2012Metric_Pad1.18x1.45mm_HandSolder
D1: white; LED_0805_2012Metric_Pad1.15x1.40mm_HandSolder
D2: 1N4148W; D_SOD-123
J1: Screw_Terminal_01x02; TerminalBlock_bornier-2_P5.08mm
J2: Conn_01x02_Pin; PinSocket_1x02_P2.54mm_Vertical
JP1: SolderJumper_2_Bridged; SolderJumper-2_P1.3mm_Bridged_RoundedPad1.0x1.5mm
K1: Relay_DPDT; HK19F
Q1: MMBT3904; SOT-23
R1, R2: 330; R_0805_2012Metric_Pad1.20x1.40mm_HandSolder
RV1: 275V; RV_Disc_D9mm_W3.5mm_P5mm
TP1: GNDD; TestPoint_Pad_D1.0mm
XF1: 500mA; Fuse_Schurter_UMZ250

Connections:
+3V3: C3.1, D2.1 (K), J2.2, JP1.2 (B), K1.A2, R1.2; also elsewhere on the board
/MCU/relay: R2.1; also elsewhere on the board
/Power/live: A1.1 (AC/L), C1.1, K1.14, RV1.1, XF1.2
/Power/neutral: A1.2 (AC/N), C1.2, J1.2, K1.24, RV1.2
GNDD: A1.3 (-Vout), C2.2, C3.2, D1.1 (K), Q1.2 (E), TP1.1; also elsewhere on the board
LINE: K1.11; also elsewhere on the board
NEUT: K1.21; also elsewhere on the board
unnamed: A1.4 (+Vout), C2.1, J2.1, JP1.1 (A)
unnamed: D1.2 (A), R1.1
unnamed: D2.2 (A), K1.A1, Q1.3 (C)
unnamed: J1.1, XF1.1
unnamed: Q1.1 (B), R2.2

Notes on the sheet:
AC relay
use cable tie for strain relief
AC to 3.3 V
Vin range: 90..264V

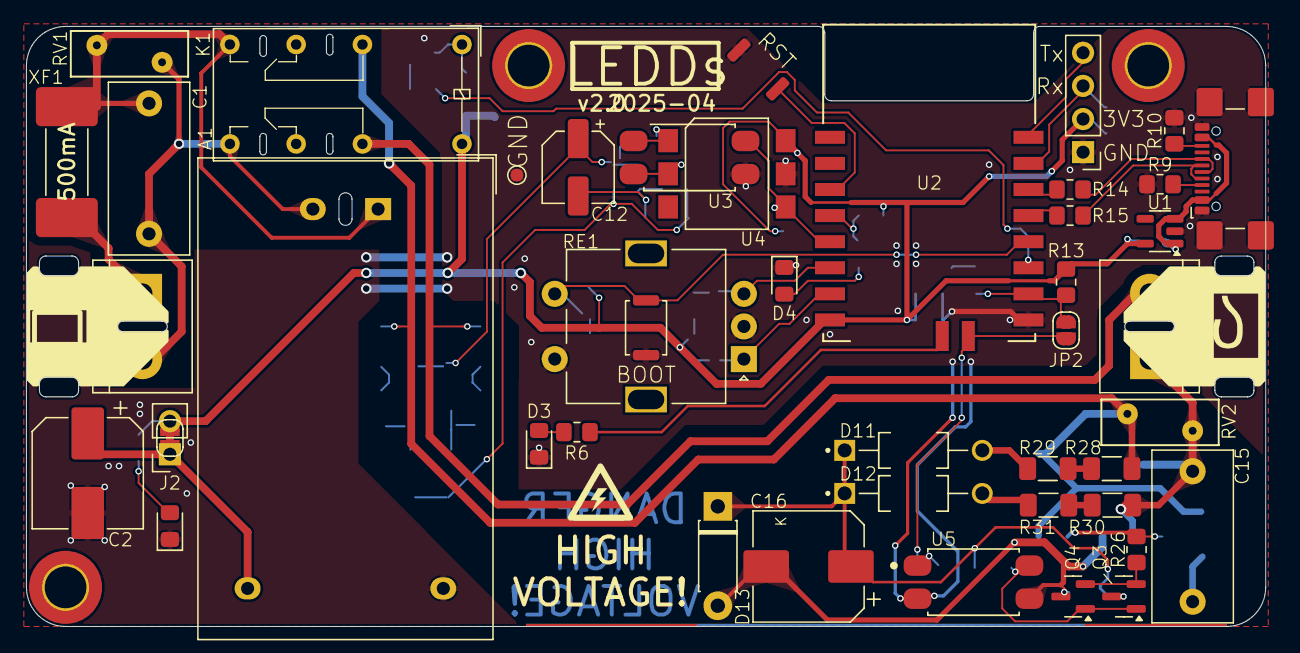
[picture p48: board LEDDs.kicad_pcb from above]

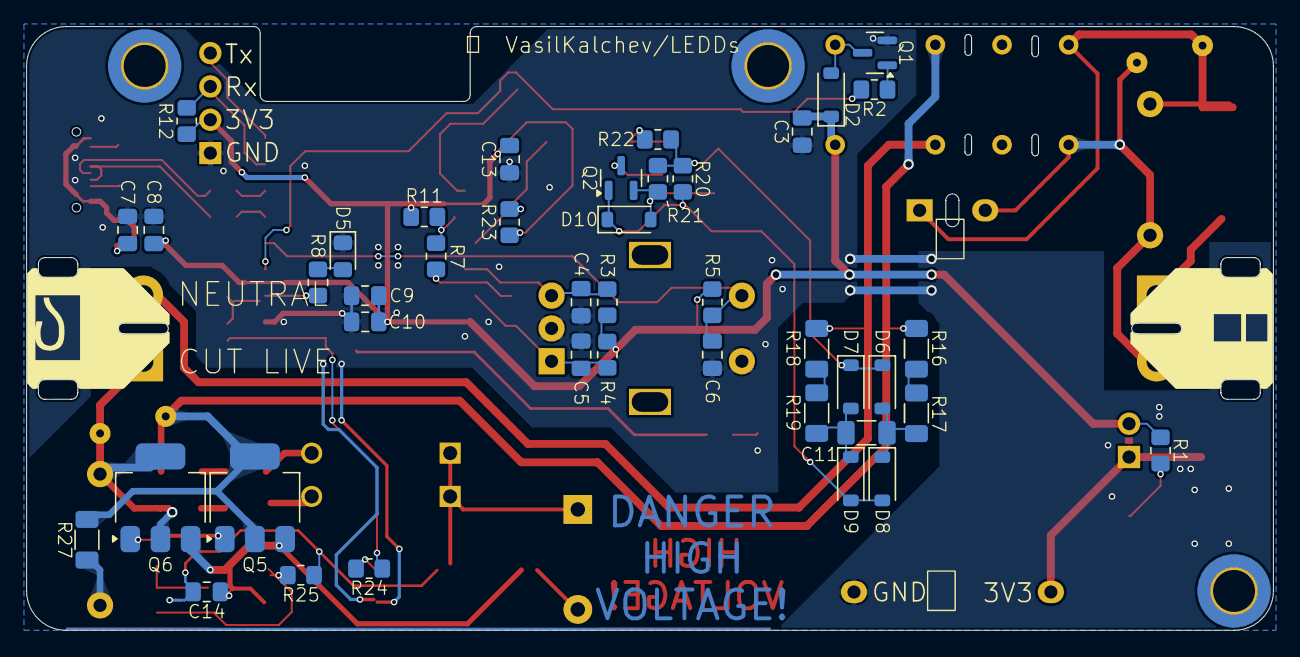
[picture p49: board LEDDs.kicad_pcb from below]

Board: 2 copper layers, 95.0 x 46.0 mm, 91 parts (42 on the bottom side), 54 nets.

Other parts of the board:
SS1: high voltage sign; LOGO

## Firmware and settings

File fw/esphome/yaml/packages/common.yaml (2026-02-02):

substitutions:
  device_friendly_name: "LEDDs 2"

  # user configuration
  dim_step: 6.25  # 10 % | 6.25 %
  gamma_correct: 2.2
  minimum_level: 15 %
  restore_mode: ALWAYS_OFF  # ALWAYS_OFF | ALWAYS_ON
  transition_length: 300 ms
  feedback_blink_length: 40 ms

  # IDs
  light_id: dimmer_light
  ac_dimmer_id: ac_dimmer_output
  rotary_encoder_id: rotary_encoder_sensor
  rotary_encoder_btn_id: rotary_encoder_btn_sensor
  feedback_led_id: red_led

  # pinout
  led_2_pin: GPIO2
  zc_pin: GPIO3
  re_b_pin: GPIO4
  re_a_pin: GPIO5
  led_1_pin: GPIO6
  gate_pin: GPIO7
  led_3_pin: GPIO8
  re_btn_pin: GPIO9
  relay_pin: GPIO10

# =====

esp32:
  variant: esp32c3
  framework:
    type: esp-idf
    version: recommended

logger:
    level: WARN  # NONE < ERROR < WARN < INFO < DEBUG < VERBOSE < VERY_VERBOSE

wifi:
  ap:

captive_portal:

improv_serial:
  next_url: https://github.com/VasilKalchev/LEDDs/tree/v2.0

ota:
  platform: esphome
  on_begin:
    then:
      - output.turn_off:
          id: ${ac_dimmer_id}

# =====

light:
  - platform: monochromatic
    id: ${light_id}
    name: "Bulb"
    output: ${ac_dimmer_id}
    icon: "mdi:lightbulb-variant"
    default_transition_length: ${transition_length}
    gamma_correct: ${gamma_correct}
    restore_mode: ${restore_mode}
    effects: !include monochromic_effects.yaml

  - platform: monochromatic
    id: red_led
    name: "LED: red"
    output: led1
    icon: "mdi:led-outline"
    entity_category: "config"
    default_transition_length: 1000 ms
    restore_mode: RESTORE_DEFAULT_ON
    initial_state:
      state: on
      brightness: 100 %

  - platform: monochromatic
    id: blue_led
    name: "LED: blue"
    output: led2
    icon: "mdi:led-outline"
    entity_category: "config"
    default_transition_length: 1000 ms
    restore_mode: RESTORE_DEFAULT_ON
    initial_state:
      state: on
      brightness: 100 %

  - platform: monochromatic
    id: white_led
    name: "LED: white"
    output: led3
    icon: "mdi:led-outline"
    entity_category: "config"
    default_transition_length: 1000 ms
    restore_mode: RESTORE_DEFAULT_ON
    initial_state:
      state: on
      brightness: 100 %


  - platform: status_led
    id: blue_status_led
    pin:
      number: ${led_1_pin}
      allow_other_uses: true


sensor:
  - platform: rotary_encoder
    id: ${rotary_encoder_id}
    name: "Knob"
    icon: "mdi:knob"
    internal: true
    pin_a: ${re_a_pin}
    pin_b: ${re_b_pin}
    min_value: -1
    max_value: 1
    publish_initial_value: true
    restore_mode: ALWAYS_ZERO
    filters:
      - debounce: 20 ms
    on_clockwise:
      then:
        - if:
            condition:
              - binary_sensor.is_off: ${rotary_encoder_btn_id}
            then:
              - script.execute:
                  id: feedback_blink
                  condition: !lambda 'return id(${light_id}).remote_values.get_brightness() < 1.0;'
              - light.dim_relative:
                  id: ${light_id}
                  relative_brightness: ${dim_step} %
                  transition_length: 0 ms
            else:
              - script.execute:
                  id: feedback_blink
                  condition: !lambda 'return id(${light_id}).get_current_effect_index() < (uint32_t)id(${light_id}).get_effect_count();'
              - script.execute:
                  id: walk_effects
                  forward: true

    on_anticlockwise:
      then:
        - if:
            condition:
              - binary_sensor.is_off: ${rotary_encoder_btn_id}
            then:
              - script.execute:
                  id: feedback_blink
                  condition: !lambda 'return id(${light_id}).remote_values.get_state() > 0.0;'
              - light.dim_relative:
                  id: ${light_id}
                  relative_brightness: !lambda 'return (${dim_step} * -1) / 100.0;'
                  transition_length: 0 ms
            else:
              - script.execute:
                  id: feedback_blink
                  condition: !lambda 'return id(${light_id}).get_current_effect_index() > 0;'
              - script.execute:
                  id: walk_effects
                  forward: false



binary_sensor:
  - platform: gpio
    id: ${rotary_encoder_btn_id}
    name: "Knob button"
    internal: true
    pin:
      number: ${re_btn_pin}
      inverted: true
      ignore_strapping_warning: true
    entity_category: diagnostic
    use_interrupt: true
    interrupt_type: ANY
    filters:
      - delayed_on_off: 10 ms
    on_click:
      min_length: 50 ms
      max_length: 500 ms
      then:
        - light.toggle:
            id: ${light_id}


power_supply:
  - id: ac_live
    pin:
      number: ${relay_pin}
      inverted: false
    enable_time: 100 ms
    keep_on_time: 500 ms
    enable_on_boot: false
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

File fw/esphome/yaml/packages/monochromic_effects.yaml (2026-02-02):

- pulse:
    name: "Pulse (low, fast)"
    transition_length: 4s
    update_interval: 4s
    min_brightness: 1%
    max_brightness: 50%
- pulse:
    name: "Pulse (low, slow)"
    transition_length: 7s
    update_interval: 7s
    min_brightness: 1%
    max_brightness: 50%
- pulse:
    name: "Pulse (high, fast)"
    transition_length: 4s
    update_interval: 4s
    min_brightness: 50%
    max_brightness: 100%
- pulse:
    name: "Pulse (high, slow)"
    transition_length: 7s
    update_interval: 7s
    min_brightness: 50%
    max_brightness: 100%
- pulse:
    name: "Pulse (full, fast)"
    transition_length: 3s
    update_interval: 3s
    min_brightness: 1%
    max_brightness: 100%
- pulse:
    name: "Pulse (full, slow)"
    transition_length: 10s
    update_interval: 10s
    min_brightness: 1%
    max_brightness: 100%
- flicker:
    name: "Flicker (soft)"
    alpha: 85%
    intensity: 3%
- flicker:
    name: "Flicker (intense)"
    alpha: 85%
    intensity: 4%

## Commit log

2025-03-31 Add separate gerbers
2026-01-25 V2.0 (#2)
    * **Hardware & Mechanical Design**
    * Updated design files and exports.
    * Split chassis and top plate into variants.
    * Changed enclosure folder structure.
    * Hid alignment/dimension layers; removed duplicate models.
    * Added mechanical parts and notes to schematics.
    * **Firmware**
    * Updated firmware and added new versions.
    * Introduced firmware variants and consolidated them into packages.
    * Added common.yaml.
    * Moved effects out of packages.
    * **Project Structure & Tooling**
    * Added BOM exports and fixed script permissions.
    * Updated and cleaned export folders.
    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
    [LEDDs chassis v2.0 (plastic).stl, LEDDs chassis v2.0 (resin).stl, LEDDs chassis v2.1 (plastic).stl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]
2026-02-02 Remove MAC suffix. Change framework to esp-idf.
2026-03-07 Update soldering instructions for optoisolators
    Removed instructions to solder R23 for both optoisolators.
